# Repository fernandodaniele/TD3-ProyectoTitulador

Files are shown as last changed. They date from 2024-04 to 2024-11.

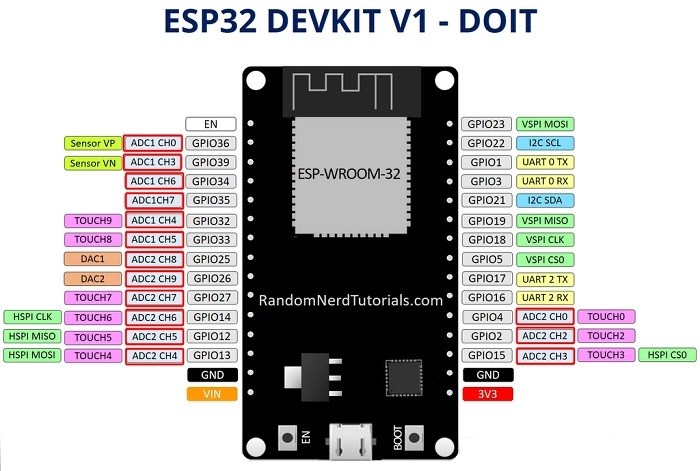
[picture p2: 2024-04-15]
Holas de datos y especificaciones/esp32_pinmap-b.jpg

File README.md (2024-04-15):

# TD3-ProyectoTitulador
El proyecto se basa en la actualización del sistema embebido del prototipo de un titulador potenciométrico automático, el cual fue realizado en el marco del proyecto PID “Abordaje multidisciplinar en la obtención de un titulador automático para el laboratorio de servicios de la Facultad Regional San Francisco”, código AMUTNSF0007673.

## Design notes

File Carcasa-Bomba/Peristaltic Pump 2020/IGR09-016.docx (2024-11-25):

DISEÑO Y CONSTRUCCIÓN DE UNA BOMBA PERISTÁLTICA DE CAUDAL VARIABLE PARA SU APLICACIÓN EN TÉCNICAS ANALÍTICAS DE LABORATORIO

Lucio Beaa, Federico M. Córdobaa, Joel F. Mercola, María E. Tavernaa, Mariana Bernarda

aGrupo de investigación sobre aplicaciones inteligentes, UTN, F R San Francisco, Av. de la Universidad 501, San Francisco, Córdoba, Argentina.

Una bomba peristáltica es un tipo de bomba de desplazamiento positivo, que es capaz de transportar líquidos de forma limpia ya que estos no entran en contacto con los componentes de la bomba. El fluido es transportado por medio de un tubo flexible situado dentro de una cubierta circular. Si bien, este tipo de bomba fue desarrollada en 1881 y se popularizó debido a su utilidad en el área de medicina, actualmente son muy requeridas en los laboratorios de química. En este sentido, estos dispositivos se emplean en equipos o instrumentos tales como cromatógrafos líquidos de alta presión, tituladores automáticos, reactores, entre otros, donde se requiere un caudal de fluido preciso y variable en ciertas ocasiones. Actualmente, el mercado ofrece este tipo de bombas con especificaciones determinadas pero con costos inaccesibles para las universidades públicas. Por esa razón, surge la necesidad de generar este tipo de equipos para usos específicos en los laboratorios de servicios del área de química.

En particular, el objetivo de este trabajo es desarrollar un modelo funcional de bomba peristáltica adaptada a las necesidades del titulador automático diseñado por el Grupo de Investigación sobre Aplicaciones Inteligentes (GISAI). Para esto se construyó un prototipo que cuenta con un motor paso a paso “Nema 17” bipolar, de 12 V; y 1,7 A; y mangueras termoplásticas del tipo PharMed BPT. El caudal impulsado por la bomba varía entre 0,2 y 10 mL/min. El motor se montó en una carcasa 3D impresa con ácido poliláctico (APL), resultando tanto el sistema de mangueras como la carcasa de la bomba adecuados para su uso en el titulador automático. El caudal en la bomba es regulado por un controlador A4988, ya que debe ser variable entre cada revolución e inversamente proporcional a la cercanía del punto final de la reacción de titulación. Esto se logra mediante la retroalimentación con el sistema de control, y un software específicamente diseñado que, realizando la conversión de señales, ajusta la velocidad de giro del rotor entre 0 y 400 rpm.

La construcción de la bomba adaptada a las condiciones requeridas por el titulador, permite el desarrollo económico de equipos que optimicen las actividades de los laboratorios involucrados, recopilando además información que permita, a futuro, trabajar estadísticamente en el desarrollo de modelos matemáticos de diversas reacciones estudiadas en otros grupos de investigación.

Palabras clave: bomba peristáltica, titulador automático, software de titulación.

Diseño basada en https://www.thingiverse.com/thing:2619479 (la pagina esta en ingles, pero explican muchas cosas de la bomba)

Modelado en 3D mediante Software SolidWorks

Mangueras:

Se optó por utilizar dos tipos de mangueras

1) Manguera PharMed BPT (de alta calidad, resistencias químicas, diseñada especialmente para aplicaciones de bombas peristálticas) – 4mm diámetro exterior – 0.8mm diámetro interior, esta se va a utilizar específicamente en la cubierta circular interior que posee la bomba y es esta la que va a soportar las periódicas y/o cíclicas deformaciones producidas por los rodillos del rotor, dadas sus propiedades este tipo de material con la que la manguera esta elaborada es capaz de otorgar una larga vida útil bajo dichas exigencias.
2) Manguera genérica silicona – 4mm diámetro exterior – 0.8mm diámetro interior, este tipo de manguera mucho más económica pero apta para su propósito, va a ser utilizada en los tramos de entrada y salida de la bomba, donde la única exigencia a la misma va a estar sometida es a la de transportar el valorante desde el recipiente a la entrada de la bomba, y luego desde la salida de la bomba hasta el otro recipiente donde se encuentra el analito, es decir no va a estar sometida a cargas mecánicas, solo al paso de los diferentes soluciones de valorante por su interior(evaluar si la silicona es apta con soluciones base o acidas no recuerdo en este caso cuales eran las que se usaban como valorantes)

Esta decisión logra una reducción en el costo dado a que la manguera 1 posee un precio elevado respecto a la manguera 2, considerando además que con dicha configuración la longitud de manguera 1 usada con respecto a la 2 es mucho menor.

El motor utilizado en la etapa final fue el mismo que se planteó en un principio “Motor Paso a Paso Nema 17”, rango voltaje apto 5 – 36V, máx corriente 1,7ª, dato que no se incluyo en el resumen es de 1.8° por paso, eso quiere decir que por revolución, es decir para lograr una vuelta entera del eje (360°) necesito que el motor de unos 200 pasos (1.8°x200 = 360°) MARCA “USONGSHINE” NUMERO SERIE “17HS4401S-DP” (capaz con eso pueden sacar algún dato extra como torque o dimensiones, peso).

La velocidad del motor va a depender de que instancia de la etapa de titulación se encuentra en un principio comenzaría a una alta velocidad para reducir tiempo y acercarse más rápido al punto final ¿? (no se si es el nombre correcto para el punto donde hay que detener la titulación, punto en la curva de valoración) y a medida que vamos llegando a dicho punto la velocidad se va a ir reduciendo para tratar de acercarnos de una manera precisa y no pasarnos del mismo.

Para probar la bomba en una primera instancia era importante denotar si al girar el rotor la misma succionaba liquido del recipiente de entrada, lo que se hizo fue girar el rotor de manera manual y se observa que el liquido comenzaba a subir por la manguera de entrada, circulaba por la manguera de la cavidad circular y salía por el final de la manguera, es decir, estaba cumpliendo su función de dosificar líquido.

La próxima prueba fue probar la repetitividad de la misma para determinar si esta iba a ser apta para un proceso de titulación donde se requieren precisas dosis de volumen. Para ello se utilizó un control electrónico (parte de Fer) donde se cargo un programa que determinaba que la bomba iba a dar una X cantidad de pasos, se corrio dicho programa siempre a la misma velocidad 10 veces. En este caso el fluido a dosificar era agua de la canilla, se tomó como densidad 1 gr/mL y se utilizó una balanza que es capaz de pesar centésimas de gramo (apreciación + - 0.01gr). Se calibro la balanza, se coloco un recipiente que iba a almacenar el agua una vez dosificada y se puso en 0 la misma. (luego de correr el programa cada vez se volvía a poner en 0 la balanza. Tras las 10 series de dosificaciones, determinamos que la bomba era apta para el proceso de titulación dado a que obtuvo una excelente repetitividad y la desviación más grande entre el valor máximo y mínimo dosificado fue de 0.05gr, valores obtenidos:

NO LOS ENCUENTRO CUANDO LOS TENGA LOS PASO, O PODEMOS INVITAR ALGO

Para poder calibrar la bomba y que la misma dosifique los volúmenes que el usuario le indique es necesario obtener un valor de (pasos/mL) en nuestro caso optamos por tomar como unidad de volumen mL porque es la unidad de volumen que se involucra en la titulación, y para obtener esos pasos/mL/ (pasos dados por el motor, es decir cuantos pasos debe de realizar el motor para que la cantidad de volumen dosificado sea de 1 mL) este valor no era posible obtenerlo mediante formulas y/o software de diseño dado que depende de muchas variables que no están a nuestro alcance, por ello se optó por un método experimental para obtenerlo, se decidió realizar una serie de 10 dosificaciones nuevamente, donde se le indica a la bomba que realice una cierta cantidad de pasos X a una velocidad X, siempre los mismos para esa serie. Nuevamente como en el caso anterior se pesaron las dosificaciones y se obtuvo el valor correspondiente de volumen (era equivalente 1gr – 1mL al ser agua), con los diez valores de volumen se obtuvo un promedio. Una vez obtenido ese valor promedio se procedió a realizar una regla de tres simple,

1ml - pasos/mL (incognita)

Volumen promedio - pasos/mL X (utilizado arbitrariamente en el programa)

Luego de obtener el valor deseado, fuimos capaces de especificar la cantidad de mL que queríamos que dosifique la bomba, y se obtuvieron nuevamente excelentes resultados, en varias ocasiones se le indico a la bomba dosificar volúmenes de 5mL, 10mL y 50mL, donde las desviaciones nuevamente entre valores máximos y mínimos no supero los 0.05gr, no se observó un incremento en la desviación del volumen objetivo con respecto al volumen real dosificado a medida que el volumen objetivo era mayor.

Durante el periodo de pruebas la bomba funcionó sin ningún inconveniente mecánico, no se observaron deformaciones ni fracturas en las partes poliméricas impresas en 3D.

El material utilizada fue PLA acido poliláctico marca Grilon, este material tiene la ventaja de ser fácil de imprimir y de bajo costo, por lo que no requiere maquinas profesionales ni costosas, cualquier impresora 3d del mercado puede imprimirlo. Esto no hace de ninguna manera que presente malas prestaciones mecánicas, este polímero presenta gran resistencia mecánica, es un metarial rigido, no presenta buena resistencias química pero en esta aplicación no se requiere de dicha propiedad dado a que el fluido no esta en contacto con ninguna parte mecánica, siempre fluye por el interior de las manguera.

Luego de todos los analices podemos estar casi seguros que la misma va a poder cumplir la función para la cual fue creada, la titulación, sin mayores inconvenientes. Hoy en día una bomba peristáltica de dichas prestaciones y con la misma precisión en el mercado tiene costos que exceden a los alcances de los proyectos de investigación de la facultad, es por ello que al ser diseñada y fabricada íntegramente por nosotros hace que sus precios se reduzcan ampliamente, incluso así teniendo que comprar las partes comerciales (motor, tornillería, manguera) se adapta muy bien al presupuesto, destacando que dicha reducción de costos no lleva asociadas perdidas de calidad y precisión en el proceso.

FALTAN PONER IMÁGENES (imágenes reales o de diseño) Y DATOS DE LAS PRUEBAS DE DOSIFICACIONES (con las pruebas se puede armar alguna tabla)

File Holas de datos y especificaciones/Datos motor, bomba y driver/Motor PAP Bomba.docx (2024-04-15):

El motor utilizado para la bomba es un Nema 17 de tipo paso a paso, modelo US-17HS4401S

- Tipo: Bipolar.
- Voltaje: 12V.
- Corriente: 1.7A
- Torque: 4000g/cm.
- Modelo: 17HS4401, 17HS series size 42mm.
- Angulo de pasos de 1.8 Grados.
- No. Pasos: 200.
- No. de Cables: 4.
- Resistencia de la fase: 1.5 ohms.
- Inductancia de la bobina: 2.8mH.
- Cables preparados para soldar.
- Largo de cableado: 25 Cm aprox.
- Eje de 5mm Diametro / 20 mm de Largo.
- Conexiones: AZUL: B- / VERDE: A- ROJO: A+ / AMARILLO: B+

https://www.luisllamas.es/motores-paso-paso-arduino-driver-a4988-drv8825/

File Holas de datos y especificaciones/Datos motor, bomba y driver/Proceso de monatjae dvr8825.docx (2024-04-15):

### REGULACIÓN DE INTENSIDAD (CHOPPING)

Ambos controladores disponen de reguladores de intensidad incorporados. El motivo es que los motores paso a paso de cierto tamaño y potencia, como por ejemplo los NEMA 17 o NEMA 23, necesitan tensiones superiores a las que podrían soportar las bobinas por su corriente nominal.

Por ejemplo, supongamos que tenemos un motor NEMA 17 con 1.2A de intensidad nominal y 1.5 Ohm de resistencia por fase. Según la ley de Ohm deberíamos aplicar 1.8V a cada bobina para que circule la intensidad nominal de 1.2A. Sin embargo, con esa tensión el motor ni se movería.

Para el que el motor funcione correctamente necesitamos aplicar una tensión superior. En este ejemplo, la tensión nominal podría ser 12V. Pero si aplicáramos 12V directamente, nuevamente por la ley de Ohm, pasarían 8A por la bobina, lo cual destruiría el motor en poco tiempo.

Por este motivo, los controladores incorporan un limitador de intensidad, que permiten alimentar el motor a tensiones nominales superiores a las que es posible por su resistencia e intensidad máxima admisible.

Por supuesto, la ley de Ohmn debe cumplirse en todo momento por lo que, continuando con nuestro ejemplo, cuando alimentemos el motor a 12V por la bobina pasará inevitablemente 8A.

El limitador interrumpe la señal proporcionando una señal pulsada PWM de forma que el valor promedio de la intensidad que atraviesa la bobina es la intensidad nominal del motor. Terminando nuestro ejemplo, el limitador de tensión aplicaría el pulso durante el 15% del tiempo y mantendrá el motor apagado el 85% restante.

A este mecanismo de limitación de intensidad se le denomina Chopping.

Para regular la intensidad que proporcionara el limitador y ajustarlo al valor del motor que vayamos a emplear ambas placas disponen de un potenciómetro que regula la intensidad del limitador.

Una forma de estimar la intensidad del regulador es medir la tensión (Vref) entre el potenciómetro y GND y aplicar una fórmula que depende del modelo, que encontraréis en la tabla del principio de la entrada.

Estas fórmulas dependen el valor Rs de las resistencias ubicadas en la placa que pueden variar en función del fabricante. Los valores típicos también aparecen en la tabla, pero debéis comprobar el valor de las resistencias que monta vuestra placa.

Por ejemplo, con los valores de Rs habituales las fórmulas se reducen a:

Modelo | Rs | Fórmula reducida
A4988 | 50 | I_max = 0,625 * V_ref
A4988 | 100 | I_max = 1,25 * V_ref
A4988 | 200 | I_max = 2 ,2* V_ref
DRV8825 | 100 | I_max = 2 * V_ref

No obstante, el valor obtenido mediante esta medición es sólo una aproximación y puede ser inexacto, por lo que lo emplearemos sólo como una calibración inicial, y terminaremos el ajuste fino midiendo la corriente real que proporciona el controlador al motor mediante un amperímetro.

# PROCESO DE MONTAJE

El proceso de montaje del A4988 o el DRV8825 no es demasiado complicado. La única parte que resulta un poco peliaguda es el proceso de ajuste y calibración del regulador de intensidad.

Ambos controladores son bastante robustos y difíciles de romper cuando están trabajando, si respetamos las necesidades de disipación de calor (cuando sea necesario).

Pero son extremadamente sensibles a desconectar el motor cuando el controlador está alimentado. Hacer esto causará, casi con total seguridad, que dañemos el controlador.

En general, evitar conectar o desconectar cualquier cable mientras el controlador esté alimentado.

Por otro lado, el potenciómetro del regulador de intensidad no tiene tope físico, por lo que es posible pasar de cero al máximo de valor sin danos cuenta, y podríamos dañar accidentalmente el motor.

Para no dañar ni el controlador ni el componente, debemos seguir siempre el proceso rigurosamente sin saltarnos ningún paso.

- Conectar el driver a tensión, sin el motor y sin microstepping
- Medir con un voltímetro la tensión entre GND y el potenciómetro
- Ajustar el potenciómetro hasta que la tensión sea el valor proporcionado por la fórmula
- Apagar el montaje
- Conectar el motor, interponiendo en medio un amperímetro
- Realizar con cuidado el ajuste fino del potenciómetro, hasta que la intensidad sea la nominal del motor
- Apagar el montaje
- Retirar el amperímetro, y conectar el motor definitivamente
- Conectar Arduino al montaje

Como hemos dicho, el hecho de que vayamos a usar posteriormente microstepping influye en el valor limite que debemos fijar en el regulador de intensidad.

Si no vamos a usar Microstepping, podemos aplicar aumentar el límite del regulador de intensidad hasta el 100% de la intensidad nominal del motor.

Si vamos a usar Microstteping, el valor que hemos medido es el 71% del que luego circulará realmente por la bobina. Por tanto, en el amperímetro debemos ajustar el 71% de la intensidad nominal del motor.

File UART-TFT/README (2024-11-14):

Este programa controla un display MCUFRIEND y se comunica por UART con un ESP32
Despues de cada comando, el ESP32 envia "/" para indicar que es el fin del comando

Comando enviado     --  Se espera         			 -- Acción

"A" INICIO_CAL 		    "K/"                 -- Inicio calibracion
"B" FIN_CAL    		    "K/"                 -- Fin calibracion     -- Calcula la recta de ajuste y guarda los valores en flash
"C" LECTURA_POTENCIAL   Valor del electrodo + "/" -- leer el valor actual del eletrodo * 100
"D" GRABA_BUFFER4 	    "K/"                 -- grabar el valor actual del electrodo en el bufferA - flash
"E" GRABA_BUFFER7		"K/"                 -- grabar el valor actual del electrodo en el bufferB - flash
"F" GRABA_BUFFER1O		"K/"                 -- grabar el valor actual del electrodo en el bufferC - flashF
"G" INICIO_TIT		    "K/"                 -- iniciar proceso de titulacion
"H" LECTURA_PH   	     SIN USAR           -- Lee el valor de pH convertido
"I" CANCELA_TIT		    "K/"+"J/"+Valor vol. gastado+"/" -- Finaliza de titulacion
Ningungo, se lee        "J/"+Valor vol. gastado+"/"		    -- La envia el ESP al Arduino cuando se llega al volumen de corte
"K" INICIO_LIMPIEZA	    "K/"                 -- señal de inicio de limpieza
"L" FIN_LIMPIEZA		"K/"                 -- señal de fin de limpieza
"M" LEE_VOLUMEN 		volumen de corte    -- lee el volumen de corte
"N" GUARDA_VOLUMEN	    "K/"                 -- envia el valor del volumen de corte configurado
"O" ESTADO_AGITADOR	      SIN USAR          -- Consulta estado agitador
"P" HABILITA_AGIT		"K/"                 -- señal de agitador on
"Q" DESHALIBITA_AGIT	"K/"                 -- señal de agitador off

Comandos que faltan
podría ser alguna señal de conexion wifi / bluetooth
podría ser alguna señal de guardado en memoria SD

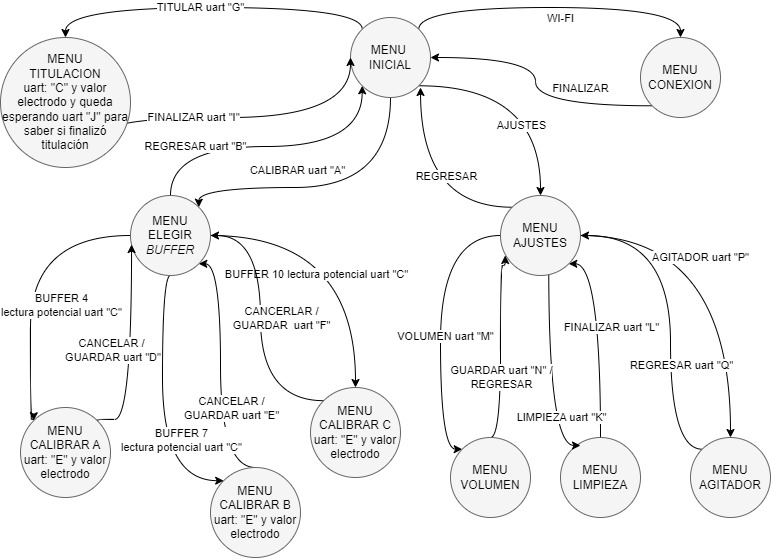
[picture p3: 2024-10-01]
UART-TFT/MEF menu titulador.jpg

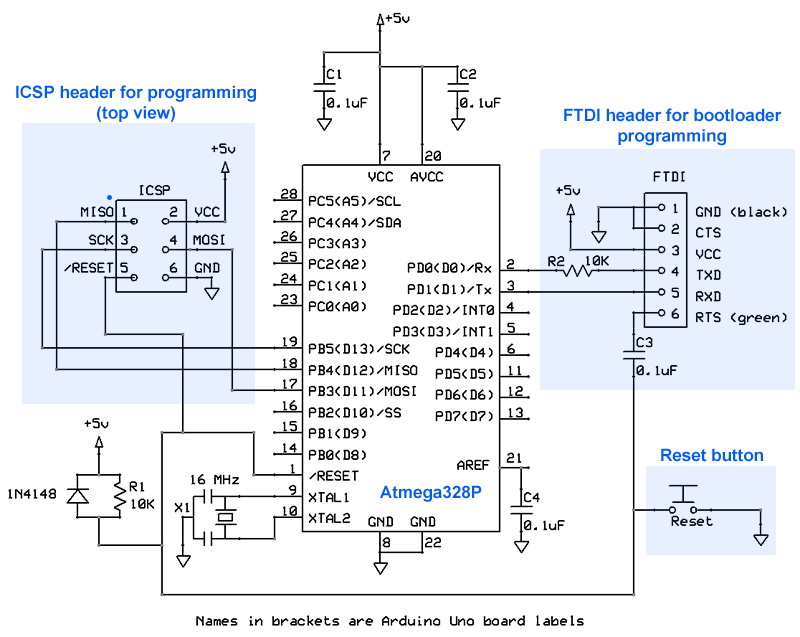
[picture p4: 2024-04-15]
Holas de datos y especificaciones/Wire_Wrapped_Atmega132_e.png

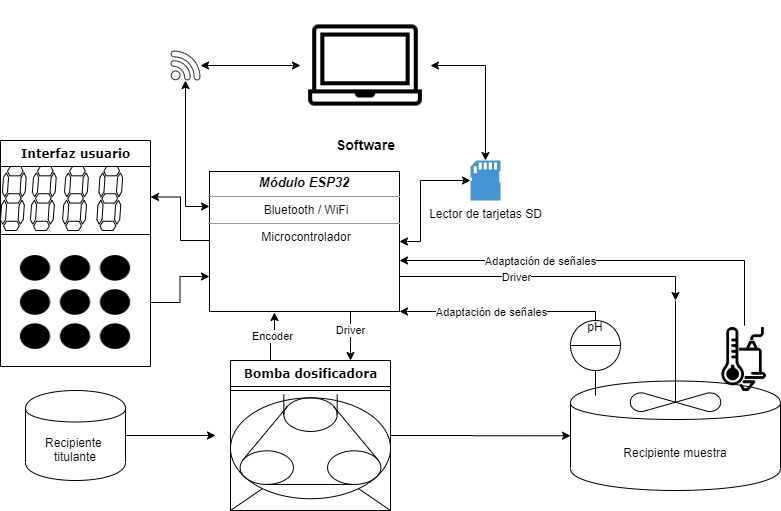
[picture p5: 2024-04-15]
Holas de datos y especificaciones/Diagrama titulador-Anterior.jpg

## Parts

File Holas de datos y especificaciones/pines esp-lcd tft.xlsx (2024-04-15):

Arduino pin | LCD Shield Pin | Use | ESP32 | Observaciones
3.3V | 3.3V | Power | 3.3
5V | 5V | Power | Externo
GND | GND | Power
A0 | LCD_RD | LCD Control | GPIO2
A1 | LCD_WR | LCD Control / Touch Data | GPIO4
A2 | LCD_RS/ TOUCH_XM | LCD Control / Touch Data | GPIO15 | Ver de usar otro, con wifi no se puede usar ADC2 | probar con 5 | 32
A3 | LCD_CS /TOUCH_YP | LCD Control | GPIO33 |  | probar con 18 | 33
A4 | LCD_RST LCD | Reset | GPIO32
D2 | LCD_D2 | LCD Data | GPIO26
D3 | LCD_D3 | LCD Data | GPIO25
D4 | LCD_D4 | LCD Data | GPIO17
D5 | LCD_D5 | LCD Data | GPIO16
D6 | LCD_D6 | LCD Data/ Touch Data | GPIO27
D7 | LCD_D7 | LCD Data / Touch Data | GPIO14
D8 | LCD_D0 / TOUCH XP | LCD Data | GPIO12 | probar con 32 | 5
D9 | LCD_D1 / TOUCH YM | LCD Data | GPIO13 | probar con 33 | 18
D10 | SD_CS | SD Select |  | Ver cual usar

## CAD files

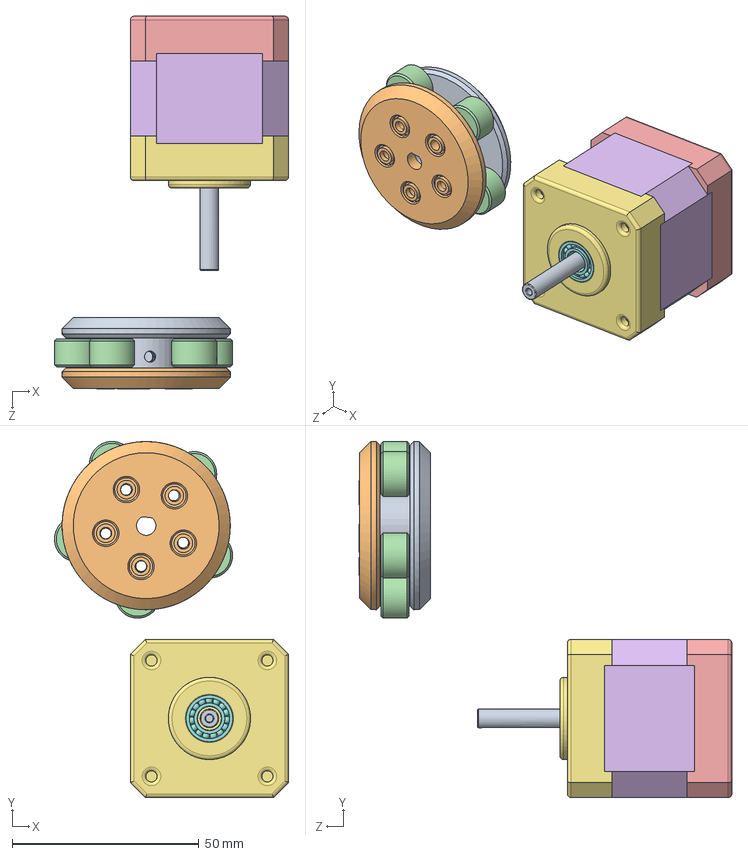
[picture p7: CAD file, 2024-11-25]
Carcasa-Bomba/Peristaltic Pump 2020/bomba.SLDASM
62.6 x 95.2 x 99.7 mm
Plato cabezal eje
Plato cabezal
Perno Precision x 5
Buje x 5
Step motor part 1
step motor orta parça
Step motor part 2
instrument ball bearing_68_am x 2
step motor part 4

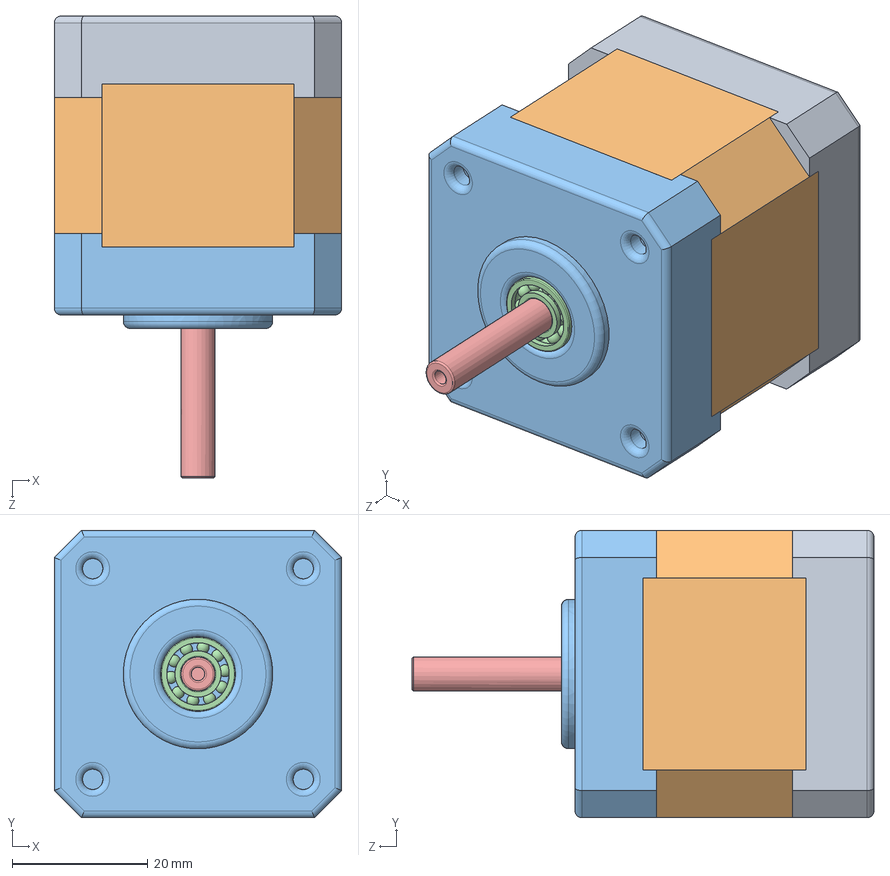
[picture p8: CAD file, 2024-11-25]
Carcasa-Bomba/Peristaltic Pump 2020/STEP MOTOR SON.SLDASM
42.3 x 42.3 x 68.0 mm
Step motor part 1
step motor orta parça
Step motor part 2
instrument ball bearing_68_am
step motor part 4

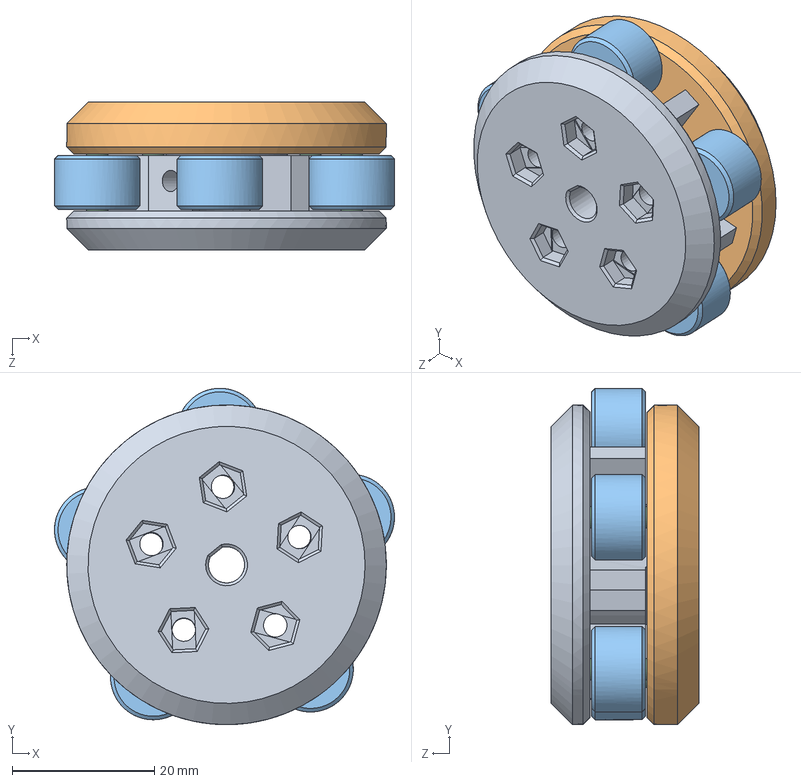
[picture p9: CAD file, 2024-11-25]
Carcasa-Bomba/Peristaltic Pump 2020/Cabezal.SLDASM
47.9 x 47.3 x 20.8 mm
Plato cabezal eje
Plato cabezal
Buje x 5
Perno Precision x 4

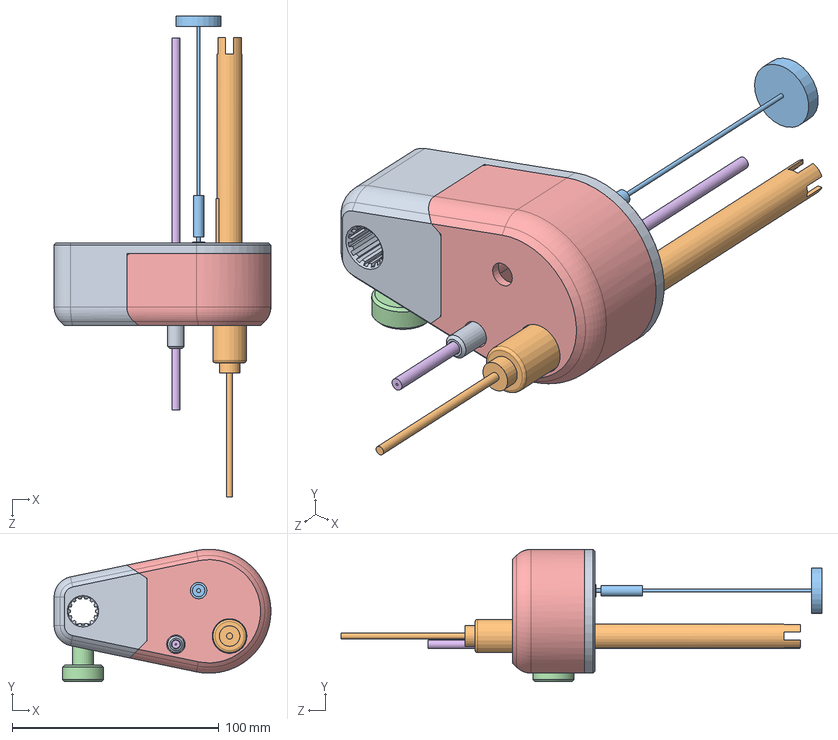
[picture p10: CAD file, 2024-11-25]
Carcasa-Bomba/Cabezal completo.SLDASM
105.0 x 64.1 x 232.9 mm
Cabezal
electrodo
BATIDOR
Tornillo apriete
Tapa cabezal
Manguera cabezal
Tornillo Fix 3 x XX x 3

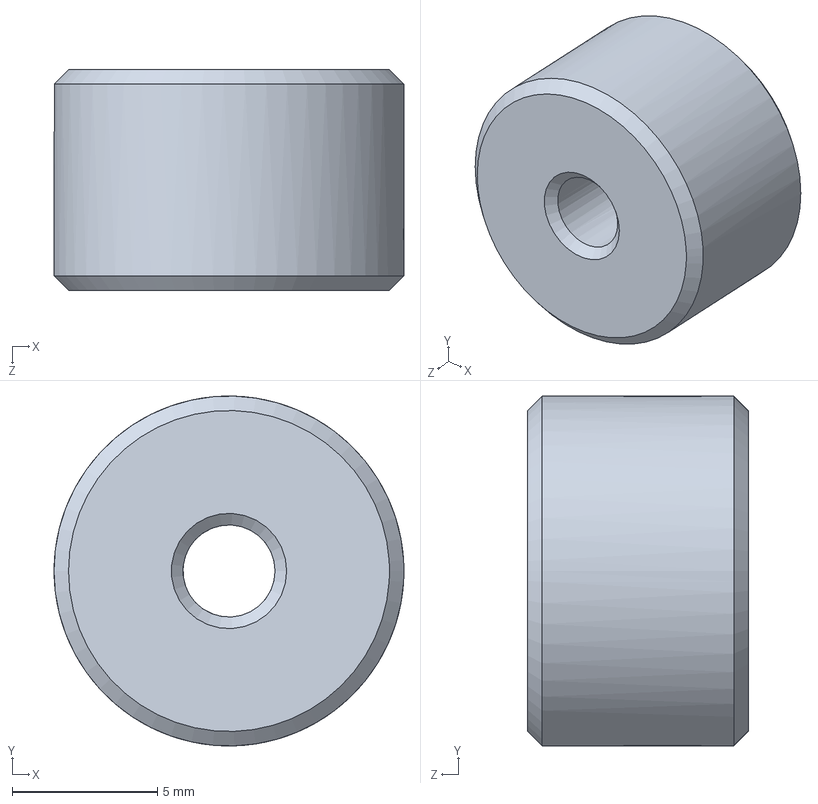
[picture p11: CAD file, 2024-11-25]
Carcasa-Bomba/Peristaltic Pump 2020/Buje.SLDPRT
12.1 x 12.0 x 7.60 mm

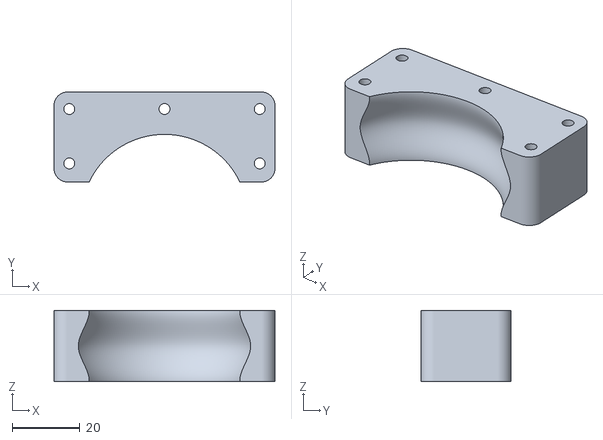
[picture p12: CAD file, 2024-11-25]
Carcasa-Bomba/Peristaltic Pump 2020/STL/Apoyo (Suelto).STL
65.0 x 26.5 x 21.0

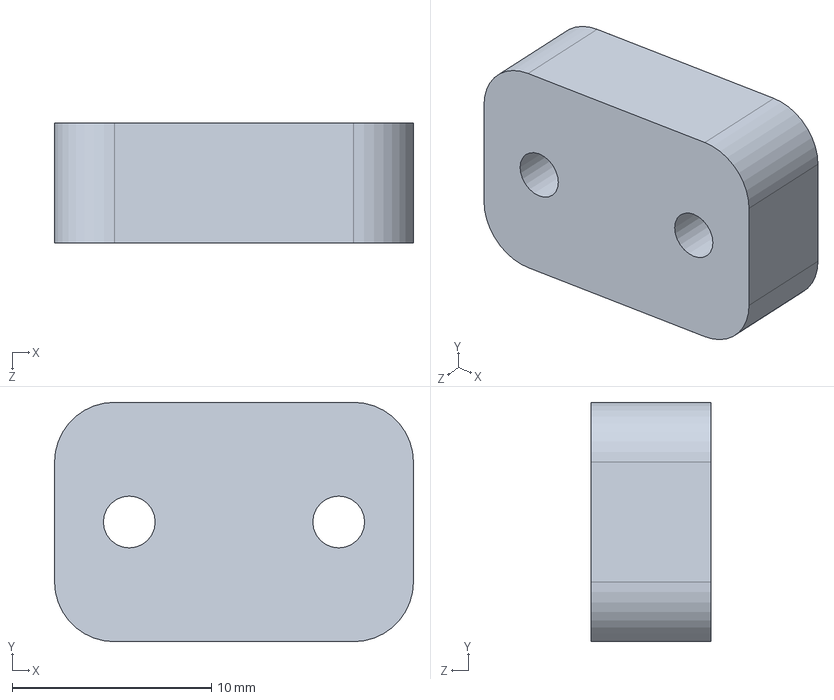
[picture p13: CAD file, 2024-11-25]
Carcasa-Bomba/soporte lapiz tuerca.SLDPRT
18.0 x 12.0 x 6.00 mm

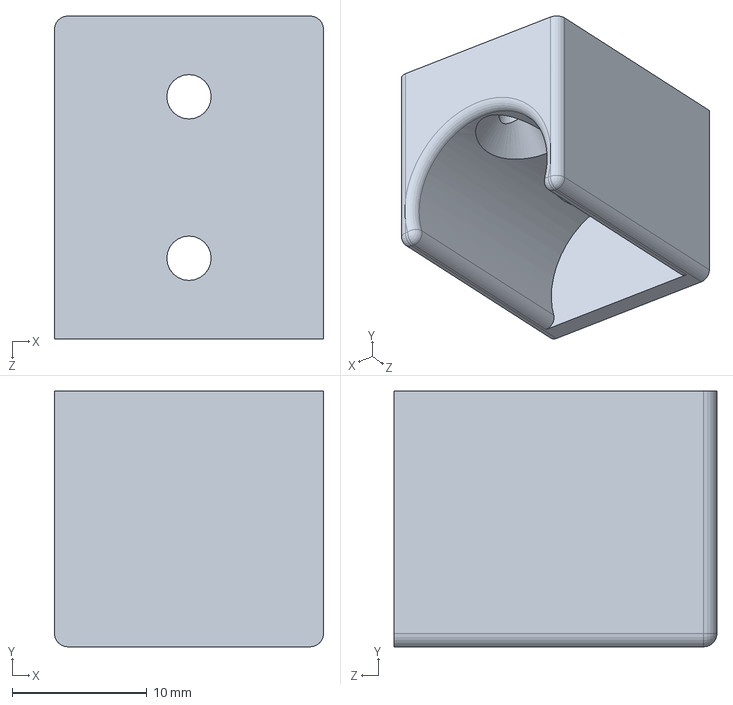
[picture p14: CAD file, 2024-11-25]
Carcasa-Bomba/Apoya protector electrodo.SLDPRT
20.0 x 19.0 x 24.0 mm

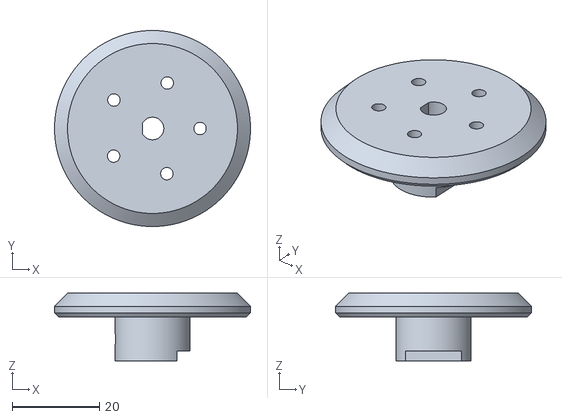
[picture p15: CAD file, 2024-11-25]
Carcasa-Bomba/Peristaltic Pump 2020/STL/Cabezal eje.STL
45.0 x 45.0 x 15.5

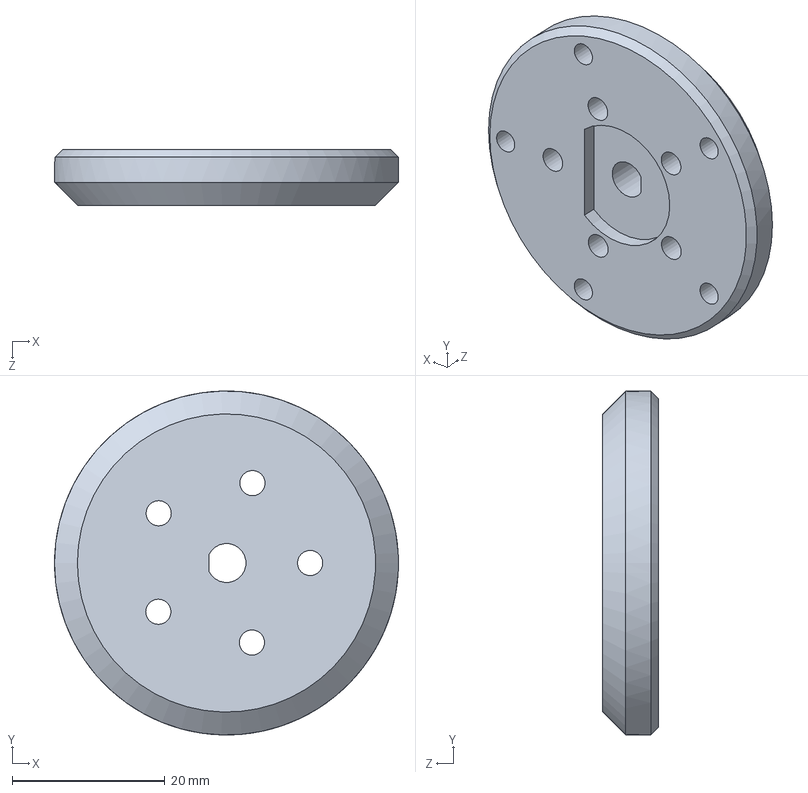
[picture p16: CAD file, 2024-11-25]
Carcasa-Bomba/Peristaltic Pump 2020/Plato cabezal.SLDPRT
45.0 x 45.0 x 7.30 mm

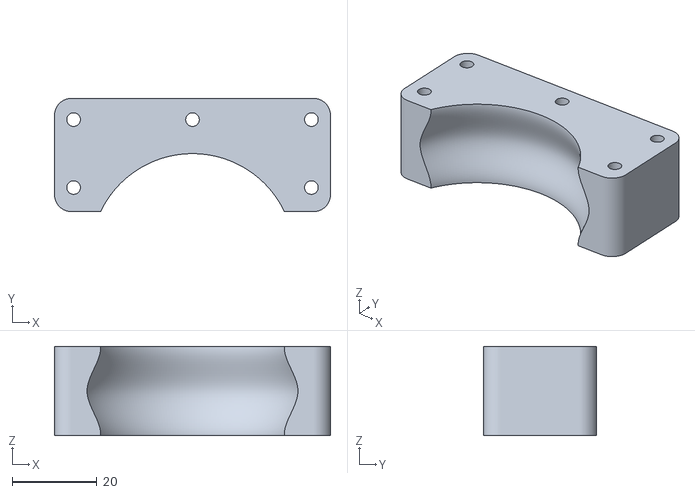
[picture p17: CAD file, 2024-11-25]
Carcasa-Bomba/Peristaltic Pump 2020/STL/Apoyo (Medio).STL
65.0 x 26.7 x 21.0

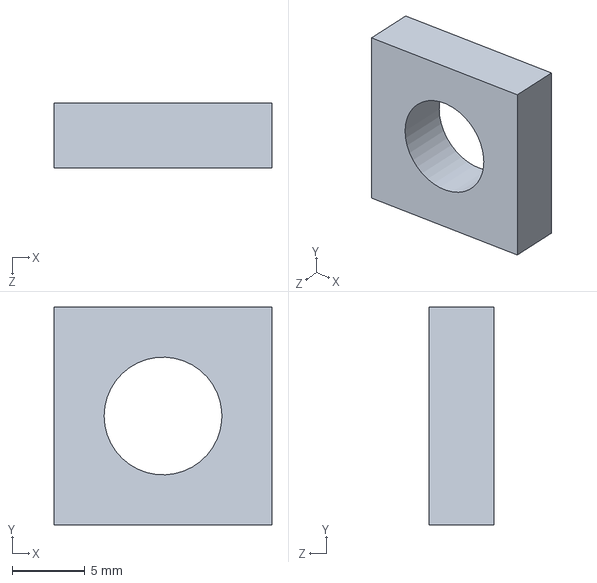
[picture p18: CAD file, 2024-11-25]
Carcasa-Bomba/soporte conector potencia.SLDPRT
15.0 x 15.0 x 4.50 mm

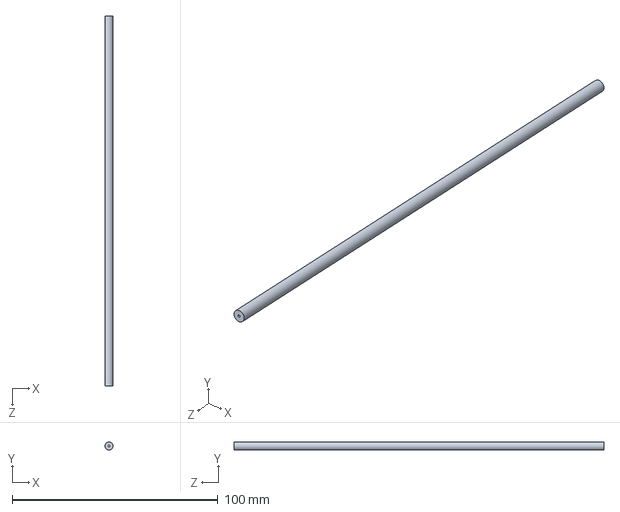
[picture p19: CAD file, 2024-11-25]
Carcasa-Bomba/Manguera cabezal.SLDPRT
4.00 x 4.00 x 180.0 mm

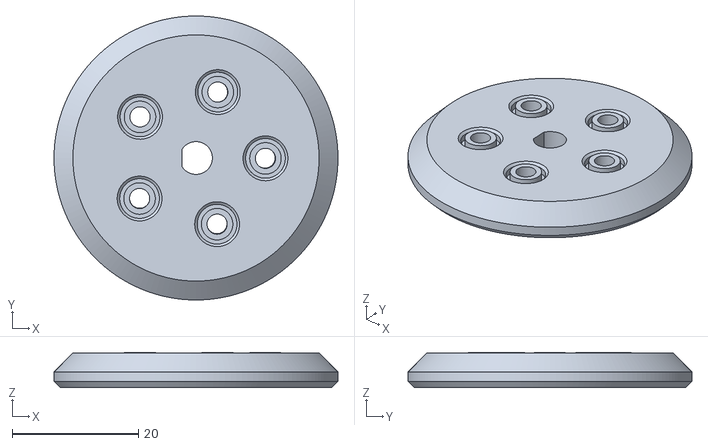
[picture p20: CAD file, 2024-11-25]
Carcasa-Bomba/Peristaltic Pump 2020/STL/Cabezal tapa.STL
45.0 x 45.0 x 5.60

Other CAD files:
Carcasa-Bomba/BATIDOR.SLDPRT
Carcasa-Bomba/Peristaltic Pump 2020/rodillos.SLDPRT
Carcasa-Bomba/Peristaltic Pump 2020/STL/Apoyo (Ajustado).STL
Carcasa-Bomba/Peristaltic Pump 2020/apoyo.SLDPRT
Carcasa-Bomba/Apoya protector electrodo.3MF
Carcasa-Bomba/Barra 12.SLDDRW
Carcasa-Bomba/Barra 12.SLDPRT
Carcasa-Bomba/Basetitulador.3MF
Carcasa-Bomba/Basetitulador.SLDPRT
Carcasa-Bomba/Buje.3MF
Carcasa-Bomba/Cabezal.3MF
Carcasa-Bomba/Cabezal.SLDPRT
Carcasa-Bomba/Carcasa tapa.3MF
Carcasa-Bomba/Carcasa tapa.SLDPRT
Carcasa-Bomba/Conector potencia y motor.SLDPRT
Carcasa-Bomba/Logo_SensorPH.SLDPRT
Carcasa-Bomba/Peristaltic Pump 2020/Apoyo (Normal).SLDPRT
Carcasa-Bomba/Peristaltic Pump 2020/Buje.3MF
Carcasa-Bomba/Peristaltic Pump 2020/Cabezal.3MF
Carcasa-Bomba/Peristaltic Pump 2020/Manguera flexible.SLDPRT
Carcasa-Bomba/Peristaltic Pump 2020/Perno Precision.SLDPRT
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

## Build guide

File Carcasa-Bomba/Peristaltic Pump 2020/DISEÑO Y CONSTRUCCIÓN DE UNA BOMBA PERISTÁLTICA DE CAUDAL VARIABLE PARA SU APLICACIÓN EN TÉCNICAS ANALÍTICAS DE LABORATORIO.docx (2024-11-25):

DISEÑO Y CONSTRUCCIÓN DE UNA BOMBA PERISTÁLTICA DE CAUDAL VARIABLE PARA SU APLICACIÓN EN TÉCNICAS ANALÍTICAS DE LABORATORIO

Lucio Beaa*, Federico M. Córdobaa, Joel F. Mercola, María E. Tavernaa, Mariana Bernarda

aGrupo de investigación sobre aplicaciones inteligentes, UTN, F R San Francisco, Av. de la Universidad 501, San Francisco, Córdoba, Argentina.

*luciogbea@gmail.com

Resumen

Una bomba peristáltica es un tipo de bomba de desplazamiento positivo, capaz de transportar líquidos de forma limpia, al no entrar en contacto con los componentes de la bomba. El fluido es transportado por medio de un tubo flexible situado dentro de una cubierta circular. Estos dispositivos se emplean en equipos o instrumentos donde se requiere un caudal de fluido preciso y variable en ciertas ocasiones. Actualmente, el mercado ofrece este tipo de bombas con especificaciones determinadas, pero con costos inaccesibles para las universidades públicas. Por esa razón, el objetivo de este trabajo es desarrollar un modelo funcional de bomba peristáltica en la automatización de un titulador diseñado por el Grupo de Investigación sobre Aplicaciones Inteligentes (GISAI). La construcción y prueba de la bomba adaptada a las condiciones requeridas por el titulador, permite el desarrollo económico de equipos que optimicen las actividades de los laboratorios involucrados, recopilando además información que permita, a futuro, tomar decisiones estratégicas sobre los resultados obtenidos.

Palabras Claves: bomba peristáltica, titulador automático, impresión 3D.

Introducción

Las bombas peristálticas son dispositivos que se emplean para transportar diferentes tipos de líquidos. Existen muchas aplicaciones de estas bombas en el sector de medicina, laboratorios de I+D, farmacia y alimentos, entre otros [1]. En el área de las valoraciones potenciométricas, este tipo de bomba es empleada para la automatización del caudal del valorante que requiere la medición.

Existen varios estudios en relación al diseño y construcción de bombas peristálticas. En general, los trabajos reportados, analizan el principio de funcionamiento [2], la construcción [3] y las necesidades y especificaciones del diseño [4]. Leephakpreeda (2008) [5] menciona la importancia de las características de flujo de la bomba peristáltica para su diseño y uso óptimos. Koch et al. (2009) [6] discutieron sobre el diseño y las características de las microbombas basadas en tubos de polimetilsiloxano. Recientemente, Kommu et al. (2014) [1] reportaron la construcción de una bomba peristáltica usando un motor paso a paso y un microcontrolador LPC2148 para la automatización de la dosificación de valorante en valoraciones potenciométricas.

Nótese que existen relativamente pocos trabajos acerca del uso de bombas peristálticas y su funcionamiento en valoraciones potenciométricas. Por otro lado, actualmente las bombas comerciales en el área de titulación automática son generalmente de alto costo, lo que las vuelve inaccesibles para su uso en diversos proyectos dentro de las universidades públicas.

Por lo expuesto anteriormente, el objetivo de este trabajo es diseñar y construir una bomba peristáltica empleando para elaboración de la carcasa, tecnología de impresión 3D. Además, el dispositivo se utilizará para la automatización del control de caudal de valorante en el desarrollo de un prototipo de titulador automático.

Procedimiento experimental

El procedimiento experimental de este trabajo cuenta de dos partes que incluyen: 1) el diseño y construcción de la bomba y 2) el control del caudal del valorante.

1) Diseño y construcción de la bomba peristáltica

Para el diseño y construcción de la bomba, se consideró el trabajo realizado por Florez-Altamirano (2018) [7] y los estudios publicados por la organización independiente y sin fines de lucro “Fundación iGEM (International Genetically Engineered Machine)” [8].

En este sentido, se llevaron adelante los siguientes pasos:

i) elección del motor, control de giro y velocidad del motor

ii) elección de materiales para mangueras y carcasa

2) Control del caudal de valorante

A fin de chequear su correcto funcionamiento en la automatización del caudal de valorante, se efectuó la comunicación entre la bomba y el circuito electrónico. Esto permite hallar y variar la cantidad de caudal necesario para realizar los ensayos. A tales efectos, el caudal se adquiere por el módulo ESP32, que incluye un microprocesador dual Core de 32 bits y WiFi integrado. El ESP32 realiza las siguientes funciones: i) se comunica con la pantalla táctil, que brinda soporte a una interfaz de usuario; ii) controla el motor de la bomba; realiza la medición del potencial de un electrodo de pH; iii) controla el motor del agitador de la solución; iv) almacena los resultados en una memoria SD; y v) los muestra en una página web [9].

Resultados y discusión

A continuación, se muestran los resultados relacionados a las etapas metodológicas propuestas.

1) Diseño y construcción de la bomba peristáltica

El motor seleccionado para accionar la bomba es el motor paso a paso bipolar Nema 17 marca “Usongshine”, con un rango de voltaje apto de 5 a 36V, torque de 42 N.cm, máxima corriente 1,7A, de 1.8° por paso, lo que implica que para lograr una vuelta entera del eje (360°) el motor debe dar unos 200 pasos. Se eligió como controlador del motor el A4988, por su disponibilidad en el mercado y su bajo costo. Por otro lado, las prestaciones de control son ampliamente compatibles con el motor seleccionado permitiendo que, a través de un software desarrollado para tal fin, se pueda controlar la velocidad del motor. Esta velocidad influye directamente en el caudal de la bomba, lo que otorga la posibilidad de obtener una cantidad precisa del fluido necesario para las reacciones químicas, como así también para que la valoración inicie a una alta velocidad y vaya disminuyendo a medida que se acerca el punto final de la titulación.

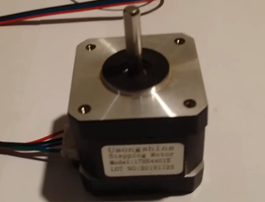
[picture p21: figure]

Fig. 1. Motor Nema 17 “Usonghine”

El diseño de las piezas mecánicas se basó en una bomba peristáltica de precisión. Para el modelado 3D se empleó el software SolidWorks®. La impresión de la carcasa, rotor y cubeta exterior se realizó con ácido poliláctico (PLA) Grilon, que ofrece facilidad en la impresión a bajo costo y que, a su vez, no requiere de impresoras profesionales sofisticadas, presentando gran resistencia mecánica. Si bien este polímero no ofrece en general buena resistencia hacia el ataque de sustancias químicas, en el desarrollo de la carcasa no se requiere esta característica dado que el fluido no estará en contacto con ninguna parte mecánica, fluyendo permanentemente por el interior de los tubos flexibles. La figura 2 muestra las partes impresas de la bomba.

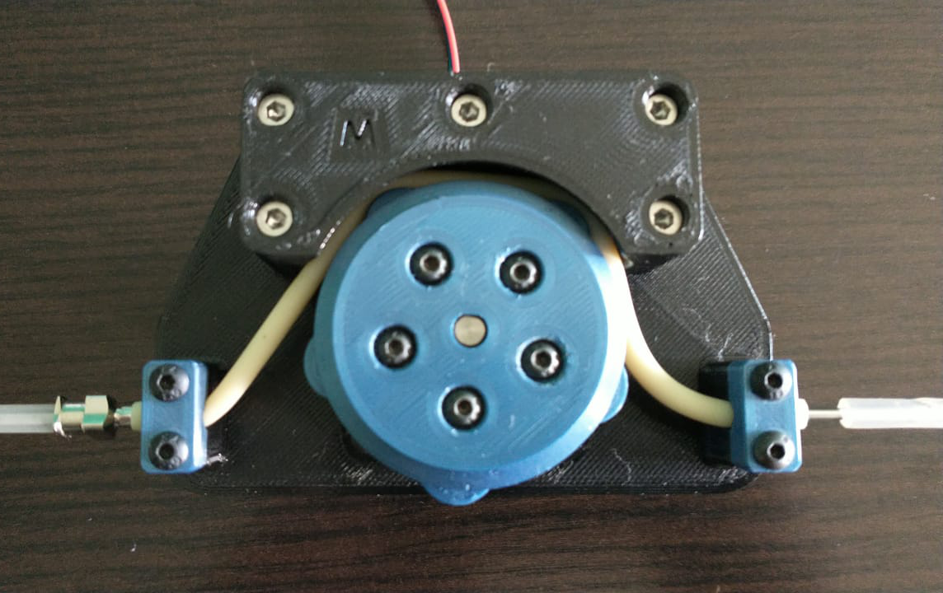
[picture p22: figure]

Fig. 2. Vista frontal de la bomba

En relación con la selección de tubos flexibles o mangueras, se utilizaron dos tipos. Por un lado, una manguera PharMed BPT (de alta calidad, resistencia química, diseñada especialmente para aplicaciones de bombas peristálticas de 4 mm de diámetro exterior y 0,8 mm de diámetro interior), se empleó en la cubierta circular interior que posee la bomba y que soportará las deformaciones cíclicas producidas por los rodillos del rotor. Gracias a las propiedades mencionadas, este tipo de material es capaz de otorgar una larga vida útil bajo dichas exigencias.

Por otro lado, se utilizaron mangueras genéricas de silicona (de 4mm diámetro exterior y 0.8mm diámetro interior) para los tramos de entrada y salida de la bomba, donde la única exigencia será la de transportar el valorante desde el recipiente contenedor hacia la entrada de la bomba, y luego desde la salida de la bomba hasta el recipiente de valoración, por lo cual no va a estar sometida a sobrecargas mecánicas excepto el flujo de paso de las diferentes soluciones de valorante por su interior. Esta decisión logra una reducción en el costo total de la bomba, ya que las mangueras genéricas tienen un precio considerablemente menor respecto de las PharMed BPT.

2) Control del caudal del valorante

Para verificar el funcionamiento de la bomba en el control de caudal de valorante se realizó el giro del rotor de manera manual y se observó que el líquido comenzó a ascender por la manguera de succión, circulando por la cavidad circular y descargando por el extremo opuesto. Cuando se detuvo el movimiento del rotor, el líquido dejó de fluir, lo que indica que la bomba cumple su función.

Para que la bomba dosifique los volúmenes requeridos por el usuario, es necesario obtener un valor que determine la cantidad de pasos del motor que se necesitan para que el volumen de fluido transportado sea de 1 mL (pasos/mL). En este caso se opta por tomar como unidad de volumen mL por ser la unidad de volumen más habitual en la metodología de titulación. Este valor no fue posible obtenerlo mediante fórmulas y/o software dado que depende de diversas variables que involucran tanto el diseño mecánico del motor como el del proceso de succión y que no pueden ser modelizadas mediante las técnicas aplicadas en este estudio. Por esta razón, se llevó adelante una serie de 10 dosificaciones, donde se le indicó a la bomba que realice una cierta cantidad de pasos arbitraria, 2500 pasos, a una velocidad constante de 93,75 rpm, determinada esta por las características propias del motor seleccionado. El volumen dosificado en cada una de las etapas de la serie de medición se registró mediante pesaje sobre una balanza de precisión. En este proceso el fluido a dosificar fue agua de red domiciliaria, con una densidad estimada de 1 g/mL y se utilizó una balanza de dos decimales con un error de ±0,01 g, recogiendo el fluido en un vaso de precipitado previamente tarado. Luego de correr el programa, en cada dosificación se registró el peso y se taró nuevamente la balanza. Esta relación entre el número de pasos y las mediciones de masa, se reporta en la Tabla 1, y la serie de mediciones arroja un peso medio de 0,70 g con un desvío estándar de ± 0,01 g.

Tabla 1. Dosificaciones para cálculo de paso

Dosificaciones N° | peso (gramos)
1 | 0,69
2 | 0,70
3 | 0,69
4 | 0,69
5 | 0,71
6 | 0,70
7 | 0,69
8 | 0,69
9 | 0,70
10 | 0,69

La ecuación 1.1 permite extrapolar la media de pesos registrada por la serie de mediciones en relación con el número de pasos elegidos, con el objetivo de encontrar el valor de pasos necesarios para la dosificación de 1 mL de valorante.

Pasos=Volumen ×(pasos medidos)/(Volumen medido)=1 mL×2500/(0,70g)×1g/(mL)=3571 pasos Ecuación 1.1

A raíz de esta medición se pudo determinar que se requieren de 3571 pasos en el motor para alcanzar la dosificación de 1,00 ± 0,01 mL.

Luego de obtener la cantidad de pasos necesaria, se realizaron nuevas series de medición con distintos volúmenes (5, 10 y 50 mL) para comprobar la precisión con la que dosifica la bomba, y se obtuvieron resultados equivalentes.

La siguiente prueba fue constatar la repetitividad de los ciclos de funcionamiento, ya que la misma es crítica para determinar si la bomba es apta para el proceso de titulación donde será requerida. Para ello se utilizó un control electrónico desarrollado exclusivamente para tal fin, y se programaron las secuencias en el controlador para que la bomba accione una cantidad determinada de pasos a la misma velocidad durante 10 dosificaciones de 1 mL. Los pesos de las 10 dosificaciones se registraron con el mismo procedimiento mencionado anteriormente. Los valores medidos para esta serie de 10 dosificaciones fueron exactamente 1 mL en cada repetición, lo que sugiere que la bomba es apta para el proceso de titulación.

Finalmente, durante las pruebas se revisó visual y sonoramente la bomba. No se observaron deformaciones ni fracturas en las partes poliméricas impresas en 3D, ni en el resto de las piezas comerciales.

Conclusiones

En esta primera etapa, se logró diseñar y construir una bomba peristáltica con una baja inversión económica con relación a las disponibles comercialmente. Además, se logró integrar la bomba peristáltica con los componentes eléctricos, obteniendo resultados aceptables en las pruebas realizadas. Esta actividad, implicó el trabajo colaborativo y la unión de modelos electromecánicos y electrónicos, para obtener una de las funcionalidades principales del titulador. Cabe resaltar, que las disciplinas mencionadas juegan un rol fundamental en la primera etapa de planificación y desarrollo del diseño del prototipo de titulador automático, estableciendo así la posibilidad de obtener datos concretos de ensayos de prueba, para futuros análisis a través de herramientas de aprendizaje automático.

Como trabajo a futuro se plantea el diseño que soporte todos los componentes mecánicos y eléctricos, brindando una estructura completa, robusta, limpia y compacta, cerrando de esta forma un producto final, capaz de utilizarse en laboratorios de servicios. La automatización realizada, puede pensarse para ser implementada en ambientes industriales, que necesiten un proceso similar al de titulación.

Agradecimientos

A los laboratorios de agua y suelo de la Universidad Tecnológica Nacional, Facultad Regional San Francisco. A los integrantes del PID AMUTNSF0007673.

Bibliografía

[1] A. Kommu, R. R. Kanchi and N. K. Uttarkar, "Design and development of microcontroller based peristaltic pump for automatic potentiometric titration," 2014 International Conference on Communication and Signal Processing, Melmaruvathur, India, 2014, pp. 157-161, doi: 10.1109/ICCSP.2014.6949819.

[2] Mohd Firdaus Bin Mansor, "Design and prototyping a peristaltic pump," 14 November, 2008.

[3] Suhas R. Dhumal, S.S. kadam, " Design and Development of rotary Peristaltic Pump", International Journal of Science and Advanced Technology", vol.2, No.4, ApriI 20I2.

[4] E.N. Aitavade, S.D. Patil, A.N. Kadam, T.S. Mulla, "An overview of Peristaltic pump Suitable for Handling of Various Slurries and Liquids", Journal of Mechanical and Civil Engineering, 2012, pp: 19-24.

[5] Thananchai Leephakpreeda, "Experimental studies on flow characteristics of Peristaltic pump", Thammasat In!. J. Sc. Tech., vol.13, No.4, oct-Dec 2008.

[6] Corey Koch, Vicent Remcho, James Ingle, " PDMS and Tubing-based peristaltic micro pumps with direct actuation", Sensors and actuators B 135 (2009) pp:664-670.

[7] Omar Flores Altamirano, Luis Contreras, Andrea Reynoso Tapia, (2018), “Desarrollo de un prototipo de bomba peristáltica de bajo costo capaz de desplazar fluidos en ambos sentidos para diversas aplicaciones”, Universidad Iberoamericana Puebla, México.

[8] The International Genetically Engineered Machine (iGEM), Precise Peristaltic Pump by iGEM_Aachen (https://www.thingiverse.com/iGEM_Aachen), November 01, 2017, www.thingiverse.com/thing:2619479.

[9] Daniele, F., Córdoba, F., Anchino, L. Depetris, L., Bea, L., Mercol, J., SanMartino, M., Taverna, Ma. E., Yuan R., Pettiti J.,Septiembre 2020, “Titulador Automático, una experiencia de trabajo interdisciplinar”, Jornada de Ciencia y Tecnología 2020

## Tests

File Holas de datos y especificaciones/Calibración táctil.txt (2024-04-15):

MCUFRIEND_kbv ID=0x9341  240 x 320

const int XP=8,XM=A2,YP=A3,YM=9; //240x320 ID=0x9341
const int TS_LEFT=108,TS_RT=924,TS_TOP=66,TS_BOT=883;
PORTRAIT CALIBRATION     240 x 320
x = map(p.x, LEFT=108, RT=924, 0, 240)
y = map(p.y, TOP=66, BOT=883, 0, 320)
Touch Pin Wiring XP=8 XM=A2 YP=A3 YM=9
LANDSCAPE CALIBRATION    320 x 240
x = map(p.y, LEFT=66, RT=883, 0, 320)
y = map(p.x, TOP=924, BOT=108, 0, 240)
const int TS_LEFT=66,TS_RT=883,TS_TOP=924,TS_BOT=108;

Para ESP32

const int XP=12,XM=A-21,YP=A-3,YM=13; //240x320 ID=0x9341
const int TS_LEFT=126,TS_RT=905,TS_TOP=130,TS_BOT=906;
PORTRAIT CALIBRATION     240 x 320
x = map(p.x, LEFT=126, RT=905, 0, 240)
y = map(p.y, TOP=130, BOT=906, 0, 320)
Touch Pin Wiring XP=12 XM=15 YP=33 YM=13
LANDSCAPE CALIBRATION    320 x 240
x = map(p.y, LEFT=130, RT=906, 0, 320)
y = map(p.x, TOP=905, BOT=126, 0, 240)

https://os.mbed.com/users/rlanghbv/code/mcufriend_24_tft_lcd/wiki/Hardware#mcufriend-2-4-tft-lcd-shield

https://forum.arduino.cc/index.php?topic=582765.0

https://github.com/prenticedavid/MCUFRIEND_kbv

https://predictabledesigns.com/esp32-wireless-microcontroller-as-a-general-purpose-processor-using-the-arduino-ide/

https://randomnerdtutorials.com/esp32-pinout-reference-gpios/

https://randomnerdtutorials.com/esp32-adc-analog-read-arduino-ide/

http://kio4.com/arduino/curso.htm

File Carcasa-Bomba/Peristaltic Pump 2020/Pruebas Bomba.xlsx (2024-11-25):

Prueba 1
Pasos arbitrarios elegidos para el primer programa 2500
Dosificaciones N° | Mediciones (gramos)
1 | 0.69
2 | 0.7
3 | 0.69
4 | 0.69
5 | 0.71
6 | 0.7
7 | 0.69
8 | 0.69
9 | 0.7
10 | 0.69
Promedio | 0.695
 | Con estos datos ahora podriamos sacar cuantos pasos se requeriran para dosificar 1mL = 1 gr agua
 | 0.695mL - 2500 pasos | 1mL*2500 pasos/ 0.695mL = 3597 pasos
 | 1 mL - X
Con este nuevo dato de 3597 ahora podemos crear un programa en el cual no se le indique al control realizar cierta cantidad de pasos, sino que ahora podemos indicarle que cantidad de volumen queremos que la bomba dosifique dado a q conocemos la cantidad de pasos requeridos para dosificar 1mL. Con este nuevo programa realizamos una segunda prueba donde se el volumen objetivo a dosificar era de 1mL y se lograron los siguientes resultados
Prueba 2 (volumen objetivo 1mL- 1gr AGUA)
Dosificaciones N° | Mediciones (gramos)
1 | 1
2 | 1
3 | 1
4 | 1
5 | 1
6 | 1
7 | 1
8 | 1
9 | 1
10 | 1
Promedio | 1
 | En esta segunda prueba los resultados fueron mucho mas prometedores donde luego de 10 dosificaciones la desviacion estandar fue nula
Prueba 3 (volumen objetivo 5mL- 5gr AGUA)
Dosificaciones N° | Mediciones (gramos)
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

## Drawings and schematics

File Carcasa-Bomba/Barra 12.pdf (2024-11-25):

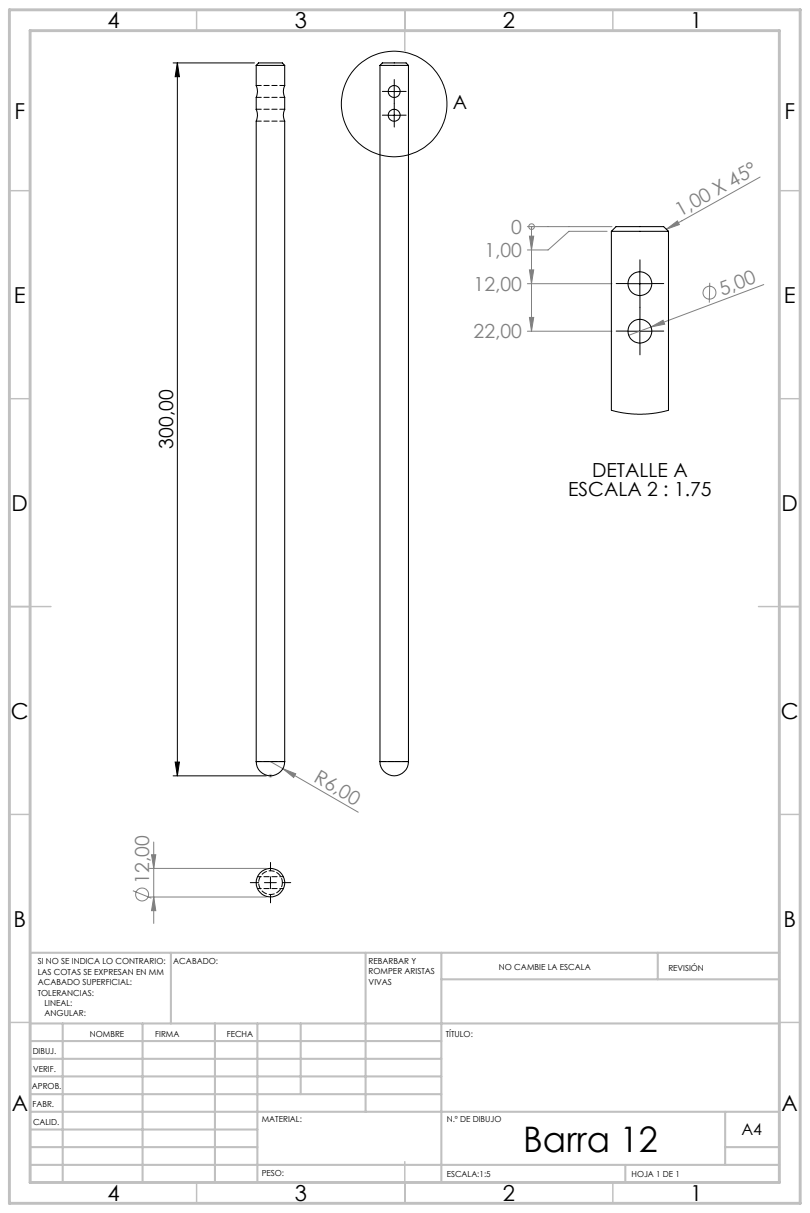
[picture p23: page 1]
DETALLE A ESCALA 2 : 1.75; ACABADO:; REBARBAR Y; ROMPER ARISTAS; NO CAMBIE LA ESCALA; REVISIÓN; ESCALA:1:5; HOJA 1 DE 1

SI NO SE INDICA LO CONTRARIO:
LAS COTAS SE EXPRESAN EN MM
ACABADO SUPERFICIAL:
TOLERANCIAS:
LINEAL:
ANGULAR:

NOMBRE | FIRMA | FECHA | | | | TÍTULO:

DIBUJ.
VERIF.
APROB.
FABR.
CALID. | | | | MATERIAL: | N.º DE DIBUJO Barra 12 | A4

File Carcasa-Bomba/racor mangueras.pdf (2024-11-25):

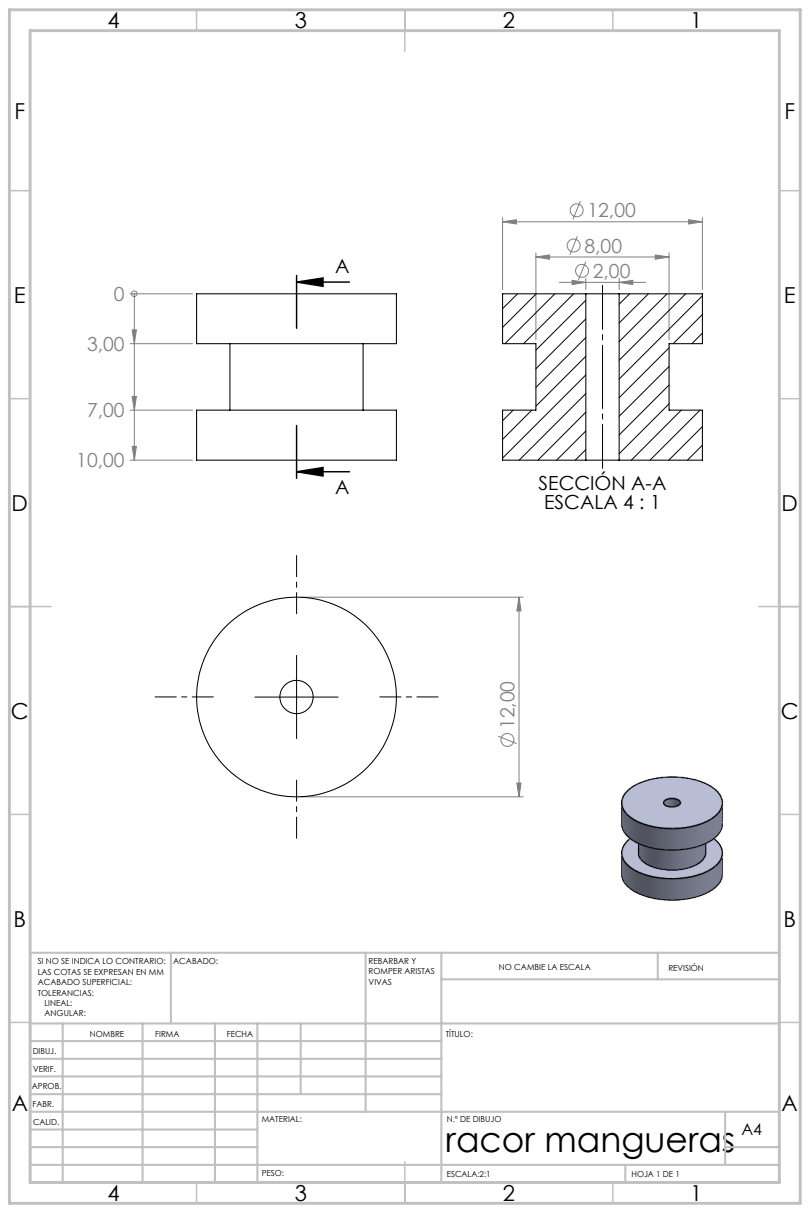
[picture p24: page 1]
SECCIÓN A-A ESCALA 4 : 1; ACABADO:; REBARBAR Y; ROMPER ARISTAS; NO CAMBIE LA ESCALA; REVISIÓN; ESCALA:2:1; HOJA 1 DE 1

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

NOMBRE | FIRMA | FECHA | | | | TÍTULO:

DIBUJ.
VERIF.
APROB.
FABR.
CALID. | | | | MATERIAL: | N.º DE DIBUJO racor mangueras | A4

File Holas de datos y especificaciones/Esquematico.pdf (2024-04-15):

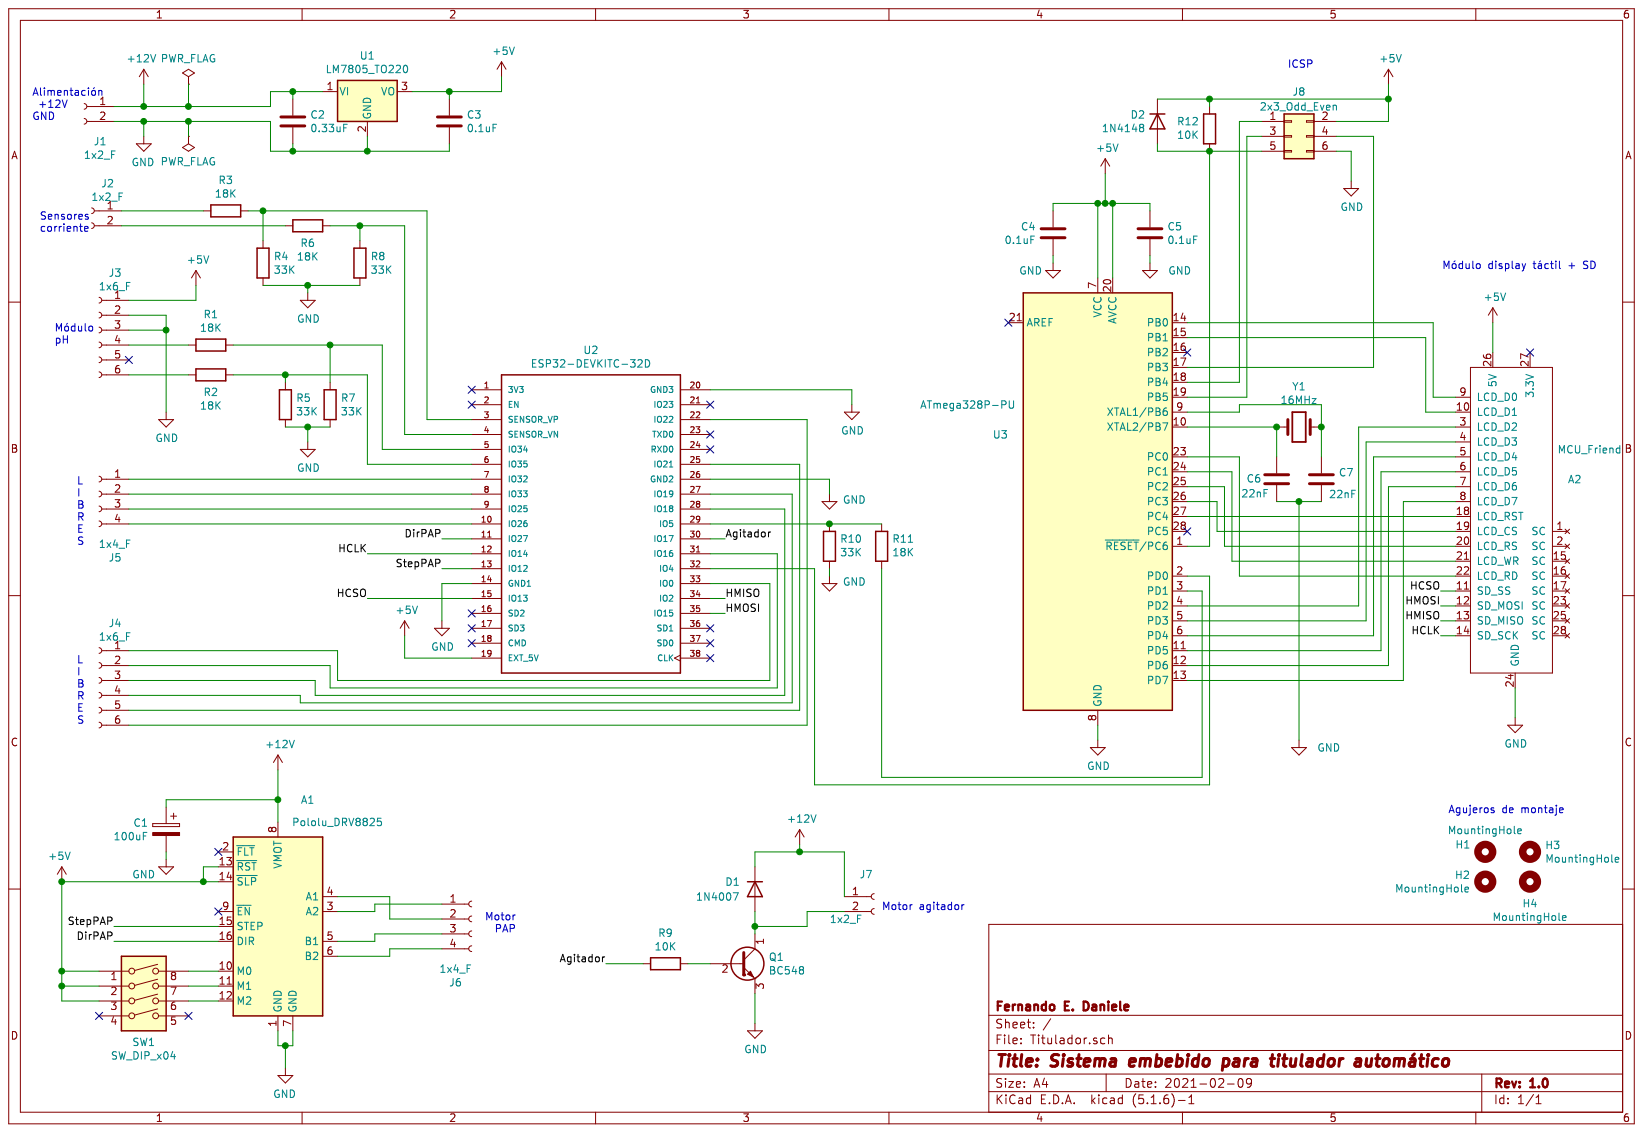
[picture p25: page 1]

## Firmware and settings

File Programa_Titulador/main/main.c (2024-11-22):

/**
 * @file main.c
 * @author Ezequiel Combina - Rodrigo Chiavassa - Guillermo Giorgis
 * @brief Titulador Automático
 * @version 0.1
 * @date 2024-11-22
 * 
 * @copyright Copyright (c) 2024
 * 
 */

#include <stdio.h>
#include <math.h>
#include <string.h>
#include <stdint.h>
#include "freertos/FreeRTOS.h"
#include "freertos/task.h"
#include "freertos/FreeRTOSConfig.h"
#include "driver/gpio.h"
#include "driver/uart.h"
#include "driver/ledc.h"
#include "esp_err.h"
#include "flash.c"
#include "uart.c"
#include "adc.c"
#include "wifi.c"
#include "sd.c"

/*==================[Definiciones]======================*/

#define T_TITULACION_MS_01ml    1180    // (1150)
#define T_TITULACION_01ml       pdMS_TO_TICKS(T_TITULACION_MS_01ml)
#define T_TITULACION_MS_1ml     T_TITULACION_MS_01ml*10
#define T_TITULACION_1ml        pdMS_TO_TICKS(T_TITULACION_MS_1ml)
#define PROCESADORA             0
#define PROCESADORB             1
#define C_MEDICIONES            10
#define T_MEDICIONES_MS         7000    // Tiempo entre cada Inyeccion
#define T_MEDICIONES            pdMS_TO_TICKS(T_MEDICIONES_MS)

// ---PWM---
#define LEDC_TIMER              LEDC_TIMER_0
#define LEDC_MODE               LEDC_LOW_SPEED_MODE
#define LEDC_OUTPUT_IO          (GPIO_NUM_12)                               // Pin de salida del PWM 
#define LEDC_CHANNEL            LEDC_CHANNEL_0
#define LEDC_DUTY_RES           LEDC_TIMER_8_BIT                            // Resolución del PWM (8 bits)
#define LEDC_DUTY_PERCENT       50                                          // Duty porcentual
#define LEDC_DUTY               ((LEDC_DUTY_PERCENT*254)/100)               // Duty al 50%. (2 ** 8) * 50% = 128
#define LEDC_FREQUENCY          (10000)                                     // Frequency in Hertz. Set frequency at 10 kHz

/*==================[Variables globales]======================*/

gpio_int_type_t P_Agitador      = GPIO_NUM_21;
gpio_int_type_t P_Enable_Bomba  = GPIO_NUM_22;
gpio_int_type_t P_Motor         = GPIO_NUM_12;
gpio_int_type_t P_Giro          = GPIO_NUM_27;

static const char *TAG_MAIN = "MAIN";

valoresPH valoresCalibracion;       // Valores de tension
RectaRegresion valoresRecta;

// Keys para acceder a los valores guardados en la memoria flash
char *key_pendiente = "Pend";
char *key_ordenada = "Ord";

Limpieza limpieza_main;

float Volumen_Inflexion;
float Vout_PH_Ant = 0.0;
float dif = 0.0;
float dif_deriv = 0.0;

float Arreglo_Volumen[200];
float Arreglo_PH[200];
int cont = 0;

extern float Volumen_Inflexion;
extern float Vout_PH;
extern int Volumen_Comp;
extern bool flag_Titular;

extern float dif_guardado;
extern float volumen_registrado;
extern float volumen_registrado_ant;

/*==================[Handles]==============================*/

QueueHandle_t S_Agitador        = NULL;
//SemaphoreHandle_t S_Limpieza = NULL;
QueueHandle_t S_Limpieza        = NULL;
QueueHandle_t S_Calibracion     = NULL;
QueueHandle_t S_Titulacion      = NULL;
QueueHandle_t S_Inyeccion       = NULL;
nvs_handle_t app_nvs_handle;

/*==================[Prototipos de funciones]======================*/

void TaskAgitador(void *taskParmPtr);
void TaskLimpieza(void *taskParmPtr); 
void TaskCalibracion(void *taskParmPtr);  
void TaskTitulacion(void *taskParmPtr);  
void TaskInyeccion(void *taskParmPtr);  
static void example_ledc_init(void); 

/*==================[Main]======================*/

void app_main(void)
{

    S_Agitador      = xQueueCreate(1, sizeof(bool));
    //S_Limpieza = xSemaphoreCreateBinary();
    S_Limpieza      = xQueueCreate(1, sizeof(limpieza_main));
    S_Calibracion   = xQueueCreate(1, sizeof(char*));
    S_Titulacion    = xQueueCreate(1, sizeof(bool));
    S_Inyeccion     = xQueueCreate(1, sizeof(limpieza_main));

    esp_rom_gpio_pad_select_gpio(P_Enable_Bomba);
    gpio_set_direction(P_Enable_Bomba, GPIO_MODE_OUTPUT);
    gpio_set_level(P_Enable_Bomba, 1);

    // Set the LEDC peripheral configuration
    example_ledc_init();
    // Set duty to 50%
    ESP_ERROR_CHECK(ledc_set_duty(LEDC_MODE, LEDC_CHANNEL, LEDC_DUTY));

    // Iniciar flash 
    ESP_ERROR_CHECK(init_nvs());

    // Lectura de los valores guardados en la UART 
    read_nvs(key_pendiente, &valoresRecta.Pendiente_Guardado);
    read_nvs(key_ordenada, &valoresRecta.Ordenada_Guardado);

    valoresRecta.Pendiente = valoresRecta.Pendiente_Guardado / 10000.0;
    valoresRecta.Ordenada = valoresRecta.Ordenada_Guardado / 10000.0;

    ESP_LOGI(TAG_MAIN, "Pendiente -> %.03f", valoresRecta.Pendiente);
    ESP_LOGI(TAG_MAIN, "Ordenada -> %.03f", valoresRecta.Ordenada);

    // // Iniciar Comunicacion Wifi
    // wifi_init();

    // Iniciar Wi-Fi en modo Access Point
    wifi_init_softap();

    // Iniciar el servidor web
    start_webserver();

    // Iniciar UART
    init_uart();

    // Iniciar ADC
    adc_init();

    // Iniciar SD
    inicializarSD();

    BaseType_t err = xTaskCreatePinnedToCore(
        TaskAgitador,                     	// Funcion de la tarea a ejecutar
        "TaskAgitador",   	                // Nombre de la tarea como String amigable para el usuario
        configMINIMAL_STACK_SIZE*2, 		// Cantidad de stack de la tarea
        NULL,                          	    // Parametros de tarea
        tskIDLE_PRIORITY+1,         	    // Prioridad de la tarea -> Queremos que este un nivel encima de IDLE
        NULL,                          		// Puntero a la tarea creada en el sistema
        PROCESADORA                         // Numero de procesador
    );

    // Gestion de errores
    if(err == pdFAIL)
    {
        ESP_LOGI(TAG_MAIN, "Error al crear la tarea.");
        while(1);    // Si no pudo crear la tarea queda en un bucle infinito
    }

    BaseType_t err2 = xTaskCreatePinnedToCore(
        TaskLimpieza,                     	// Funcion de la tarea a ejecutar
        "TaskLimpieza",   	                // Nombre de la tarea como String amigable para el usuario
        configMINIMAL_STACK_SIZE*2, 		// Cantidad de stack de la tarea
        NULL,                          	    // Parametros de tarea
        tskIDLE_PRIORITY+1,         	    // Prioridad de la tarea -> Queremos que este un nivel encima de IDLE
        NULL,                          		// Puntero a la tarea creada en el sistema
        PROCESADORA                         // Numero de procesador
    );

    // Gestion de errores
    if(err2 == pdFAIL)
    {
        ESP_LOGI(TAG_MAIN, "Error al crear la tarea.");
        while(1);    // Si no pudo crear la tarea queda en un bucle infinito
    }

    BaseType_t err3 = xTaskCreatePinnedToCore(
        TaskCalibracion,                    // Funcion de la tarea a ejecutar
        "TaskCalibracion",   	            // Nombre de la tarea como String amigable para el usuario
        configMINIMAL_STACK_SIZE*2, 		// Cantidad de stack de la tarea
        NULL,                          	    // Parametros de tarea
        tskIDLE_PRIORITY+1,         	    // Prioridad de la tarea -> Queremos que este un nivel encima de IDLE
        NULL,                          		// Puntero a la tarea creada en el sistema
        PROCESADORA                         // Numero de procesador
    );

    // Gestion de errores
    if(err3 == pdFAIL)
    {
        ESP_LOGI(TAG_MAIN, "Error al crear la tarea.");
        while(1);    // Si no pudo crear la tarea queda en un bucle infinito
    }

    BaseType_t err4 = xTaskCreatePinnedToCore(
        TaskTitulacion,                    // Funcion de la tarea a ejecutar
        "TaskTitulacion",   	            // Nombre de la tarea como String amigable para el usuario
        configMINIMAL_STACK_SIZE*2, 		// Cantidad de stack de la tarea
        NULL,                          	    // Parametros de tarea
        tskIDLE_PRIORITY+1,         	    // Prioridad de la tarea -> Queremos que este un nivel encima de IDLE
        NULL,                          		// Puntero a la tarea creada en el sistema
        PROCESADORA                         // Numero de procesador
    );

    // Gestion de errores
    if(err4 == pdFAIL)
    {
        ESP_LOGI(TAG_MAIN, "Error al crear la tarea.");
        while(1);    // Si no pudo crear la tarea queda en un bucle infinito
    }

    BaseType_t err5 = xTaskCreatePinnedToCore(
        TaskInyeccion,                    // Funcion de la tarea a ejecutar
        "TaskInyeccion",   	            // Nombre de la tarea como String amigable para el usuario
        configMINIMAL_STACK_SIZE*2, 		// Cantidad de stack de la tarea
        NULL,                          	    // Parametros de tarea
        tskIDLE_PRIORITY+1,         	    // Prioridad de la tarea -> Queremos que este un nivel encima de IDLE
        NULL,                          		// Puntero a la tarea creada en el sistema
        PROCESADORA                         // Numero de procesador
    );

    // Gestion de errores
    if(err5 == pdFAIL)
    {
        ESP_LOGI(TAG_MAIN, "Error al crear la tarea.");
        while(1);    // Si no pudo crear la tarea queda en un bucle infinito
    }

}

/*==================[Implementacion de la tarea]======================*/

void TaskAgitador(void *taskParmPtr)
{
    /*==================[Configuraciones]======================*/
    esp_rom_gpio_pad_select_gpio(P_Agitador);
    gpio_set_direction(P_Agitador, GPIO_MODE_OUTPUT);

    bool estado_agitador;

    /*==================[Bucle]======================*/
    while(1)
    {
        xQueueReceive(S_Agitador, &estado_agitador, portMAX_DELAY);
        gpio_set_level(P_Agitador, estado_agitador);
        ESP_LOGI(TAG_MAIN, "Estado Agitador = %d\n", estado_agitador);
        
        // if(estado_agitador == true)
        // {
        //   ESP_LOGI(TAG_MAIN, "Agitador Prendido\n");
        // }else{ESP_LOGI(TAG_MAIN, "Agitador Apagado\n");}
    } 
}

void TaskLimpieza(void *taskParmPtr)
{
    // ---La limpieza de la bomba va a ser regulabre y no por tiempo---
    // ---Se deben pasar DOS parámetros -> La direccion de giro y el on/off---

    /*==================[Configuraciones]======================*/
    //esp_rom_gpio_pad_select_gpio(P_Motor);
    esp_rom_gpio_pad_select_gpio(P_Giro);
    //gpio_set_direction(P_Motor, GPIO_MODE_OUTPUT);
    gpio_set_direction(P_Giro, GPIO_MODE_OUTPUT);

    // TickType_t xPeriodicity     = T_TITULACION_1ml; 
    // TickType_t xLastWakeTime    = xTaskGetTickCount();

    /*==================[Bucle]======================*/
    while(1)
    {
        xQueueReceive(S_Limpieza, &limpieza_main, portMAX_DELAY);
        gpio_set_level(P_Giro, limpieza_main.Giro_Limpieza);

        if(limpieza_main.Habilitador_Limpieza == true)
        {
            // Habilitar Enabler
            ESP_ERROR_CHECK(ledc_update_duty(LEDC_MODE, LEDC_CHANNEL));
            gpio_set_level(P_Enable_Bomba, 0);
        }
        else if(limpieza_main.Habilitador_Limpieza == false)
        {
            // Desabiilitar Enabler
            ESP_ERROR_CHECK(ledc_stop(LEDC_MODE, LEDC_CHANNEL, 0));
            gpio_set_level(P_Enable_Bomba, 1);
        }

        //xLastWakeTime = xTaskGetTickCount();
        //ESP_LOGI(TAG_MAIN, "Led Encendido");
        //ESP_ERROR_CHECK(ledc_update_duty(LEDC_MODE, LEDC_CHANNEL));
        //vTaskDelayUntil(&xLastWakeTime, xPeriodicity);
        //ESP_ERROR_CHECK(ledc_stop(LEDC_MODE, LEDC_CHANNEL, 0));
        //ESP_LOGI(TAG_MAIN, "Led Apagado");
    } 
}

void TaskInyeccion(void *taskParmPtr)
{
    // Se inyecta  una cantidad de volumen de liquido ingresada por el operario

    /*==================[Configuraciones]======================*/

    //esp_rom_gpio_pad_select_gpio(P_Motor);
    esp_rom_gpio_pad_select_gpio(P_Giro);
    //gpio_set_direction(P_Motor, GPIO_MODE_OUTPUT);
    gpio_set_direction(P_Giro, GPIO_MODE_OUTPUT);

    /*==================[Bucle]======================*/
    while(1)
    {
        xQueueReceive(S_Inyeccion, &limpieza_main, portMAX_DELAY);

        TickType_t xPeriodicity = pdMS_TO_TICKS(T_TITULACION_MS_1ml*limpieza_main.Volumen_Inyeccion); 

        //gpio_set_level(P_Giro, limpieza_main.Giro_Limpieza);

        TickType_t xLastWakeTime = xTaskGetTickCount();
        ESP_LOGI(TAG_MAIN, "Bomba Encendida");
        ESP_ERROR_CHECK(ledc_update_duty(LEDC_MODE, LEDC_CHANNEL));
        vTaskDelayUntil(&xLastWakeTime, xPeriodicity);
        ESP_ERROR_CHECK(ledc_stop(LEDC_MODE, LEDC_CHANNEL, 0));
        ESP_LOGI(TAG_MAIN, "Bomba Apagada");
    } 
}

void TaskCalibracion(void *taskParmPtr)
{
    /*==================[Configuraciones]======================*/

    char *estado_calibracion;

    /*==================[Bucle]======================*/
    while(1)
    {
        xQueueReceive(S_Calibracion, &estado_calibracion, portMAX_DELAY);
        ESP_LOGI(TAG_MAIN, "%s", estado_calibracion);

        if(strcmp(estado_calibracion, "D") == 0)
        {
            ESP_LOGI(TAG_MAIN, "Calibración PH4");
            valoresCalibracion.lectura_PH4 = Vout_filtrada_corregida;
            ESP_LOGI(TAG_MAIN, "%.03f", valoresCalibracion.lectura_PH4);
            //lectura(estado_calibracion);
        }

        if(strcmp(estado_calibracion, "E") == 0)
        {
            ESP_LOGI(TAG_MAIN, "Calibración PH7");
            valoresCalibracion.lectura_PH7 = Vout_filtrada_corregida;
            ESP_LOGI(TAG_MAIN, "%.03f", valoresCalibracion.lectura_PH7);
        }

        if(strcmp(estado_calibracion, "F") == 0)
        {
            ESP_LOGI(TAG_MAIN, "Calibración PH10");
            valoresCalibracion.lectura_PH10 = Vout_filtrada_corregida;
            ESP_LOGI(TAG_MAIN, "%.03f", valoresCalibracion.lectura_PH10);
        }

        if(strcmp(estado_calibracion, "B") == 0)
        {
            adc_calibracion();

            // Conversion de la pendiente y la ordenada a variables enteras para poder guardarlas en la falsh 

            valoresRecta.Pendiente_Guardado = (int32_t) (valoresRecta.Pendiente * 10000.0);    // Multiplicamos por 1000 para guardar 3 decimales
            valoresRecta.Ordenada_Guardado = (int32_t) (valoresRecta.Ordenada * 10000.0);      // En caso de necesitar mayor presicion multiplicar por un numero mas grande 

            // Borrado previo a la escritura (NO Necesario)
            //erase_nvs();

            // Guardado en la memoria flash 
            write_nvs(key_pendiente, valoresRecta.Pendiente_Guardado);
            write_nvs(key_ordenada, valoresRecta.Ordenada_Guardado);
        }
    } 
}

void TaskTitulacion(void *taskParmPtr)
{
    /*==================[Configuraciones]======================*/

    TickType_t xPeriodicity_1ml     = T_TITULACION_1ml; 
    TickType_t xPeriodicity_01ml    = T_TITULACION_01ml; 
    TickType_t xLastWakeTime        = xTaskGetTickCount();

    /*==================[Bucle]======================*/
    /*
    Hay que buscar el volumen inyectado para cuando dPH/dV es el valor máximo
    dPH/dVol = (pHactual-pHanterior)/(volumenActual-VolumenAnterior)
    Cuando dPH/dVol es máximo, hay que guardar como resultado volumenActual
    */
    while(1)
    {
        //xQueueReceive(S_Titulacion, &flag_Titulacion_main, portMAX_DELAY);´
        if(flag_Titular == false && cont != 0)
        {
            cont = 0;
        }

        if(flag_Titular == true)
        {
            if(cont == 0)
            {
                for(int i = 0; i < 200; i++)
                {
                    Arreglo_Volumen[i] = 0.0;
                    Arreglo_PH[i] = 0.0;
                }
                Vout_PH_Ant = Vout_PH;
                //escribeSD("Nueva titulación\n");
            }

            if(dif < 0.1)   // Dif de PH 
            {
                xLastWakeTime = xTaskGetTickCount();
                ESP_ERROR_CHECK(ledc_update_duty(LEDC_MODE, LEDC_CHANNEL));
                vTaskDelayUntil(&xLastWakeTime, xPeriodicity_1ml);
                ESP_ERROR_CHECK(ledc_stop(LEDC_MODE, LEDC_CHANNEL, 0));
                if(flag_Titular == true)
                {
                    volumen_suma_1();    
                    Arreglo_Volumen[cont] = volumen_registrado;
                }
            }

            if(dif >= 0.1)   // Dif de PH 
            {
                xLastWakeTime = xTaskGetTickCount();
                ESP_ERROR_CHECK(ledc_update_duty(LEDC_MODE, LEDC_CHANNEL));
                vTaskDelayUntil(&xLastWakeTime, xPeriodicity_01ml);
                ESP_ERROR_CHECK(ledc_stop(LEDC_MODE, LEDC_CHANNEL, 0));
                if(flag_Titular == true)
                {
                    volumen_suma_01();    
                    Arreglo_Volumen[cont] = volumen_registrado;
                }
            }

            if(volumen_registrado >= Volumen_Comp) 
            { 
                fin_titulacion();
                eliminar_volumen_registrado();
            }

            vTaskDelay(T_MEDICIONES);   // Tiempo de espera entre cada inyección 

            // Cálculo de la diferencia de PH 
            // Lo hacemos aca ya que en el proceso del ADC se esta midiendo constantemente, por lo tanto la dif siempre era muy pequeña
            dif = sqrt(pow((Vout_PH - Vout_PH_Ant), 2));
            // Calculo de la derivada 
            dif_deriv = dif / (sqrt(pow((volumen_registrado - volumen_registrado_ant), 2)));

            // Guardamos el valor anterior de PH
            Vout_PH_Ant = Vout_PH;

            // Calculo de volumen de corte 
            if(dif_deriv > dif_guardado)
            {
                registrar_volumen_inflexion(dif_deriv);
            }

            ESP_LOGI(TAG_MAIN, "\nDif -> %.02f", dif);
            ESP_LOGI(TAG_MAIN, "Dif Guardado -> %.02f", dif_guardado);
            ESP_LOGI(TAG_MAIN, "Volumen Registrado -> %.02f", volumen_registrado);
            ESP_LOGI(TAG_MAIN, "Volumen Inflexion -> %.02f\n", Volumen_Inflexion);

            Arreglo_PH[cont] = Vout_PH;
            cont++; 
        }
        vTaskDelay(pdMS_TO_TICKS(100));
    } 
}

static void example_ledc_init(void)
{
    // Prepare and then apply the LEDC PWM timer configuration
    ledc_timer_config_t ledc_timer = {
        .speed_mode       = LEDC_MODE,
        .timer_num        = LEDC_TIMER,
        .duty_resolution  = LEDC_DUTY_RES,
        .freq_hz          = LEDC_FREQUENCY,  // Set output frequency at 1 kHz
        .clk_cfg          = LEDC_AUTO_CLK
    };
    ESP_ERROR_CHECK(ledc_timer_config(&ledc_timer));

    // Prepare and then apply the LEDC PWM channel configuration
    ledc_channel_config_t ledc_channel = {
        .speed_mode     = LEDC_MODE,
        .channel        = LEDC_CHANNEL,
        .timer_sel      = LEDC_TIMER,
        .intr_type      = LEDC_INTR_DISABLE,
        .gpio_num       = LEDC_OUTPUT_IO,
        .duty           = 0, // Set duty to 0%
        .hpoint         = 0
    };
    ESP_ERROR_CHECK(ledc_channel_config(&ledc_channel));
}

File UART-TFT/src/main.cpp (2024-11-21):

/*=============================================================================
 * Autor: Fernando Ezequiel Daniele <fernandodaniele1993@gmai.com>
 * Fecha: 2020/12/21
 * Versión 2.0, fecha: 2024/11/15
 *===========================================================================*/
/***************************************************************************************************************
 * Este programa está desarrollado para un atmega328 y el framework de Arduino
 * El mismo controla un módulo de pantalla TFT 2.4" táctil (resistivo) Modelo MCUFRIEND
 * Se comunica por puerto serie con un módulo ESP32
 ***************************************************************************************************************/
#include <Arduino.h>
#include "menu.h"
#include "uart.h"
/*
 * Función setup
 */
void setup(void){
  iniciarUart ();
  iniciarMEF();
}
/*
 * Función loop
 */
void loop(void){
  actualizarMEF();
}

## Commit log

2024-04-15 Hojas datos y programa Atmega
    [pines esp-lcd tft.xlsx]
2024-09-17 Cambios PWM
2024-09-25 actualizo UART-TFT version actual
2024-10-01 Cambios ADC
2024-10-15 Envio PH por UART
2024-10-29 Proceso de Titulacion
2024-11-14 se actualiza programa Atmega con corrección de errores
    [uart.cpp]
2024-11-14 corregir calculo de volumen en el punto final
2024-11-22 Archivos de Titulacion
    [Titulacion.xlsx]
2024-11-25 disenos carcasa y bomba
    [Apoya protector electrodo.3MF, Apoya protector electrodo.SLDPRT, Apoyo (Ajustado).STL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]
